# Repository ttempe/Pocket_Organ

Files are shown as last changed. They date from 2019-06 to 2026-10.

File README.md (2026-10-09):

# Pocket Organist

A modern musical instrument instrument that fits in your pocket

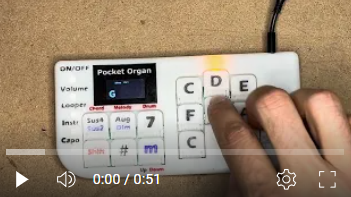
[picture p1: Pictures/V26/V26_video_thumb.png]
Main features (https://youtu.be/aTIo758k2n8)


https://www.facebook.com/Thomass-pocket-organ-109581037453852

https://archive.org/details/hopeconf2020/20200730_0900_The_Pocket_Organ.mp4

https://www.youtube.com/watch?v=AYvCeNSxtIc&list=PLIjRtindY5dAYAr6EwiWz4Ym5uZk0-Hvn

Most instruments we play today are designed around the manufacturing constrains of hundreds of years ago.
Newer instruments are often electronic versions, with the same or similar user interface.

Most really novel instruments are either:
1. excellent, but expensive small-volume brand-name products that only a dedicated musician would buy (eg: the Roli Seaboard, the Dualo Du-Touch, the Hang steel drum, the Sylphyo electronic woodwind, Artiphon Instrument 1, Jamstik ...)
2. cheap, but not good enough for a musician, lacking in depth and/or playability (eg: the roll-up keyboards, stylophone, Otamatone...)

It doesn't have to be that way, though.

The aim of this project is to develop a real musical instrument that:
* is easier to learn and play than most instruments out there
* is so affordable that aspiring musicians would consider it
* is designed to meet the expectations of real musicians (low latency, continuous expression, advanced features...)
* is convenient and versatile, fitting in your pocket and playable over headphones (includes a synthetizer) or a MIDI workstation.
* is widely available, ideally from multiple manufacturers, under the generic term "pocket organist".

See the general presentation: https://github.com/ttempe/Pocket_Organ/blob/master/Doc/2019-06-22%20Pocket%20Organ.pdf

<<<<<<< HEAD
# Hardware design

* The PCB design is published on: https://lceda.cn/ThomasTempe/Pocket_Musical_Instrument
 * The PCB is two-sided, but all the solderable components are on the same side. It is designed to use 0402 and QFN components, and is unfortunately not practical to home-etch or hand-solder ; however, you can order the PCB for a low price directly from https://szlcsc.com. If you have a China address, you can even have them do prototype pick-and-place soldering for most components (still requires SMT hand-soldering skills to finish, though). 
 * It has a LiPo battery that lasts a few hours, and a USB port for charging, and ultimately for MIDI over USB.
* The V26 enclosure is published on: https://a360.co/3xhmZ2Z and https://a360.co/4cuE1t9

# Hall effect keys: prototypes V23+

I've restarted on a different principle again end-2023.
* the keys are now 3D-printed mechanical keys with a magnet inside
* precise, fast key height is read with an SMT Hall effect sensor under each key
* a combination of spring + rubber band allows to have a nice 2-step pressure curve
* I switched to an RP2040 microrontroller, and am now debating whether to switch to CircuitPython

# capacitive touch keys: prototypes V10+

I've restarted from scratch at the beginning of 2020. This branch has:
* capacitive touch keys, which I'm trying to make somehow analog (currently under experimentation)
* a STM32F405 microcontroller
* I've re-written the whole code in Micropython. See the "Py" directory

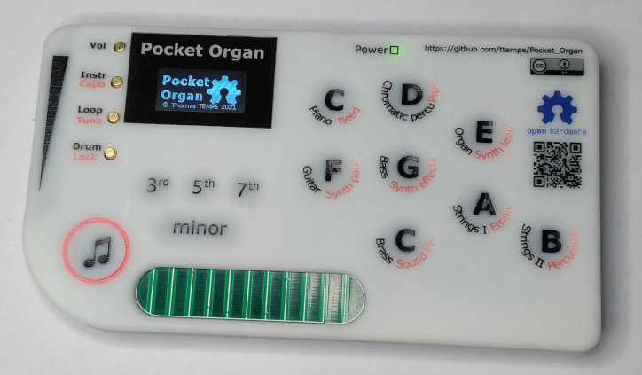
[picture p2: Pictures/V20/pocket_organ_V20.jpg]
Photo of V12 prototype


https://www.youtube.com/watch?v=Pm5AramwmKs&list=PLIjRtindY5dBtU5IU78ZPE2rcO35D6sfV

I've given up this path, as it was difficult to obtain consistent performance on all keys (especially when pressing multiple keys at once), and sourcing sensor ICs was a pain.

# Pressure-sensitive: prototypes V6 to V9

This branch of the project culminated in functional prototypes.
The analog keys use a sheet of Velostat (a pressure-sensitive, conductive plastic) and a silicone keypad.

* The device is built around a micro-controller (currently AtMEGA 32u4) and single-chip MIDI synth (SAM2695).
* code is written in C++, for the Arduino IDE. See the "src" directory.
* It is smaller but thicker than a smartphone (12.5*6*1.5cm)
* The device uses a silicone keypad for all push buttons
 * You can find a 3D model together with the enclosure, and 3D-print it, then use it to cast silicone
 * The process is partly documented here: https://www.instructables.com/id/Analog-Pressure-sensitive-Push-button/
 
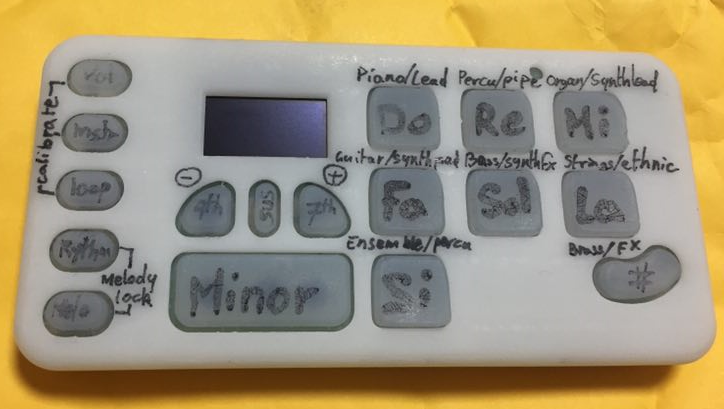
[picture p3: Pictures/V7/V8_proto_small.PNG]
Photo of V8 prototype

 
I've decided to move away from this principle, after:
* realizing that it would be a significant challenge to further lower the key mechanical resistance
* experiencing the Sylphyo's amazingly expressive capacitive touch keys.

=======
>>>>>>> efb6dceb3585c2b404cd15d46e78a298413a9809
# Musical design

This is still work in progress; and probably the most interesting part of the project.

You can play a lot of nice tunes on a piano; but they all require multiple fingers. If you come to a piano with just one finger, the result is likely to sound unpleasant.

In building the user interface, I'm trying to spare some fun for each level of play. This is why it will play chords by default. Chords are undemanding, gratifying, and you can probably find your favourite song on any tablatures repository.

More advanced play (playing one note at a time, adding expression, more exotic chord shapes...) are all there waiting for you to build up your dexterity and coordination; each step takes one more finger to play.

My ultimate goal is that the design of the instrument should progressively nudge the player on the first steps of his musical path. Each successive step should bring additional challenge, and more reward. After a few months, an assiduous player should feel confident to move to his second instrument. But if I've done my job right, the pocket organist will remain an instrument of choice.

# Features

* Under the right hand, there is one analog key for each note of the diatonic scale (Do~Si; plus a second Do). Half-tones are obtained by pressing down two adjacent notes. The keys are laid out such that notes separated by full tones are side-by-side (Do-Re-Mi, Fa-Sol-La-Si, Do).
* Under the left hand are chord shape keys, a "shift" key, and a volume slider.
* Lastly, there is a "strumming comb" slider at the bottom, that allows to easily play multiple notes of the current chord.

Additional features include:
* an 8-track looper (with color backlight codes under the note keys, similar to the Dualo Du-Touch)
* a small OLED display, to serve as a feedback loop. It will ease musical exploration and progressive disclosure by displaying the name of the note/chord being played, and name the features being used.
* function keys allow to select the instrument from the MIDI bank, tune the pitch, transpose, access the looper, and change to melody or drum pad mode.

# The end game

An Open Source Software is easy to publish: you just put it on GitHub, and call it a day. A hardware project means every single unit needs to be manufactured, ideally in a cost-effective way. 

My objective is to put 1 million devices in the hands of prospective players. That will take investment in manufacturing, distribution, and above all marketing, all things that are not in my realm.

I see myself as the person who will develop a product, then set the conditions right so that others may do the manufacturing and distribution. That means building a community, building the word-of-mouth, generating enthusiasthm and possibly looking for partners for distribution and marketing. And then, let them run away with it, and hopefully make money. The product will not reach its users unless someone makes money at every step of the process. I'm the only one who is expected to work for free. And maybe you, the supporter, the enthusiast, the player.

The project's open source nature may be a boon, or a hindrance. I might close back the source, strategically, if I think it can help someone else sell the product. Ultimately, it is better for it to be universally available as black-box commodity than open source on a dusty Github page.

# Hardware design

## Principle

Versions V23 (end-2023) and later rely on Hall effect sensors for the keys
* the key mechanism is 3D-printed.
* Each key has a magnet inside
* A silicone pad under the keys creates a smooth tactile feedback, while allowing for over- or under-pressing.
* precise, fast key height is read with an SMT Hall effect sensor under each key

These versions use an RP2040 microrontroller running CircuitPython

## Resources

* A video walk-through of how to assemble the instrument: https://youtu.be/AYvCeNSxtIc

## Main components

* The PCB design is published on: https://lceda.cn/ThomasTempe/Pocket_Musical_Instrument
 * The PCB is two-sided, but all the solderable components are on the same side. It is designed to use 0402 and QFN components, and is unfortunately not practical to home-etch or hand-solder ; however, you can order the PCB for a low price directly from https://szlcsc.com. If you have a China address, you can even have them do prototype pick-and-place soldering for most components (still requires SMT hand-soldering skills to finish, though).
 * It has a LiPo battery that lasts a few hours, and a USB port for charging, and ultimately for MIDI over USB.
* The enclosure design is published on: https://a360.co/2Yl1HuQ

# Older versions

## capacitive touch keys: prototypes V10+

I've restarted from scratch at the beginning of 2020. This branch has:
* capacitive touch keys, which I'm trying to make somehow analog (currently under experimentation)
* a STM32F405 microcontroller
* I've re-written the whole code in Micropython. See the "Py" directory

Photo of V12 prototype

I've given up this path, as it was difficult to obtain consistent performance on all keys (especially when pressing multiple keys at once), and sourcing sensor ICs was a pain.

## Pressure-sensitive: prototypes V6 to V9

This branch of the project culminated in functional prototypes.
The analog keys use a sheet of Velostat (a pressure-sensitive, conductive plastic) and a silicone keypad.

* The device is built around a micro-controller (currently AtMEGA 32u4) and single-chip MIDI synth (SAM2695).
* code is written in C++, for the Arduino IDE. See the "src" directory.
* It is smaller but thicker than a smartphone (12.5*6*1.5cm)
* The device uses a silicone keypad for all push buttons
 * You can find a 3D model together with the enclosure, and 3D-print it, then use it to cast silicone
 * The process is partly documented here: https://www.instructables.com/id/Analog-Pressure-sensitive-Push-button/
 
Photo of V8 prototype
 
I've decided to move away from this principle, after:
* realizing that it would be a significant challenge to further lower the key mechanical resistance
* experiencing the Sylphyo's amazingly expressive capacitive touch keys.

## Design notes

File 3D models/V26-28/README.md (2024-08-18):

# 3D models

Here are:
* the 3D models for printing (keys have been attached to the shell, for easier printing)
* the Fusion360 archive, for editing.

You will need to use a resin, MJF or similar printer, with a precision ~0.1mm or better.

Additionally, you will need:
* 14 cylindrical magnets, diam. 3mm, 2mm high ; North and South poles normal to the flat sides. Insertion direction is critical (test them with keyboard.monitor_readings() before inserting them, as they're a pain to get out). I get them from [the Zave Taobao shop](https://detail.tmall.com/item.htm?id=619016855032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..) (直径3mm*厚2mm)
* 14 6*7*4mm silicone key pads. I get them from [this Taobao shop](https://item.taobao.com/item.htm?id=19156845663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..)
* A custom printed 40mm*26mm*0.6mm cover plate (screen protector)

Here is an Instructable I wrote on [how to fill the lettering on the top cover](https://www.instructables.com/Writing-High-contrast-Text-on-a-Resin-3D-Print/)

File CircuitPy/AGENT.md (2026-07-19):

# Pocket Organist — Agent Guide

CircuitPython firmware for a portable MIDI chord organ with hall-effect keys, OLED display, and on-board or USB MIDI out. Targets **RP2040** (no FPU); current hardware revision is **V31** (`version.py`).

## Entry point

- `code.py` — bootstraps the app (typically `import pocket_organist`).
- `pocket_organist.py` — main application loop (`PocketOrgan` class).

## Module map

| Module | Role |
|---|---|
| `board_po.py` | **Pin allocation and hardware constants only** — mux GPIO, ADC, buttons, display SPI, MIDI, strum I2C (`strum_i2c`, `STRUM_*`), calibration tables. Import as `import board_po as board`. |
| `mux.py` | MUX shift-register addressing, hall-sensor power (GP4), `vbat_read()` / `vusb_read()`. |
| `keyboard.py` | Hall-key scanning, chord/melody/drum modes, calibration helpers. |
| `display.py` | 128×64 SSD1306 via **displayio** (`auto_refresh=False`; call `disp.refresh()` after updates). |
| `battery.py` | OCV lookup SOC gauge; charging animation via `disp_bat_charging()`. |
| `polyphony.py` | Chord/melody/drum logic and MIDI note output. |
| `looper.py` | Loop recording/playback. |
| `midi.py` | MIDI message helpers (uses `board.midi`). |
| `backlight.py` | NeoPixel key backlight; `backlight_map` in `board_po.py` maps key index to pixel. |
| `bs8112a.py` | Holtek BS8112A-3 I2C driver; `read_keys()` → 12-bit pad mask. |
| `instr_names.py` | GM instrument name tables. |
| `version.py` | Board revision number. |

Legacy / test code lives in `misc/`.

**User-facing documentation:** [`USER.md`](USER.md) — key combinations and feature descriptions for musicians. Keep it in sync when changing UI or controls.

## Application features (agent summary)

| Area | Implementation notes |
|---|---|
| **Modes** | `keyboard.mode`: chord / melody / drum via Shift+3rd/5th/7th. |
| **Volume** | Master vs channel; Shift+Vol at entry or Shift tap while Vol held (`_consume_shift_toggle`). `keyboard.ui_lock` during UI. Startup master = `127 * 75 // 100`. |
| **Capo / tuning** | `loop_capo_or_tune()` — Shift+Capo at entry or Shift tap toggles capo vs tuning. Capo: `polyphony.transpose`. Tuning: GS SysEx, `global_tuning_tenths`, peg*10, Up+Down reset. `ui_lock` throughout. |
| **Instrument** | `loop_instr()` — `high_bank` toggled by Shift tap while Instr held (Shift+Instr at entry = high bank). |
| **Metronome** | `metronome.user_wants` — persists click after looper exit when enabled via Fifth or tap tempo; auto-on from recording arm stops on exit unless `user_wants`. |
| **Looper** | In-memory `TrackStore`; CC7 baked at first note; `leave_looper()` / `apply_ui()` metronome cleanup. |
| **Melody expression** | CC11 on melody channel from key pressure; pitch bend from 7th/m keys. |
| **Display sliders** | `disp_slider()` always updates `text_zones[0].text` (dynamic titles e.g. tuning cents). |
| **Strumming** | 12-pad comb via BS8112A on I2C (GP7 SCL, GP6 SDA, addr 0x50). Hold chord root, touch pads for stacked chord tones; `keyboard.strum_keys` / `polyphony` note on/off. |

## Conventions

- **Always** `import board_po as board` — never bare `import board_po` or `from board_po import …` (except inside `board_po.py` itself).
- **GPIO stays in `board_po.py`**; mux addressing and sensor power live in `mux.py`.
- Hall sensor power: **GP4 high = off**, **GP4 low = on**. Power on before MUX/ADC reads; power off after.
- Display colors for shapes: use `0xFFFFFF` / `0x000000`, not small integers.
- Fonts: PCF in `fonts/`; preload with `font.load_glyphs()` (not dummy `Label`s).
- Battery icon: procedural `Rect` gauge at x=108 in the 8px status bar; persistent (do not clear in `Display.clear()`).
- Keep changes **minimal and focused**; match existing style; avoid drive-by refactors.

## Display layout

- Top **8 px**: status bar (latency ~x=24, battery gauge ~x=108).
- Bottom **56 px**: chord name (large font) or up to 3 lines (medium font) + tips zone.

## Battery

- Single-cell Li-ion (10440), OCV interpolation with **10% reserve** (display 0% at 10% true SOC).
- `battery.py` uses `mux.vbat_read()` / `mux.vusb_read()`; USB ≥ 4.5 V → charging animation.

## Hardware notes

- Analog keys via 3-line MUX + 2 ADCs; calibration in `board.keyb_min` / `board.keyb_range`.
- `keyboard.calibrate()` and `keyboard.test_power_settle()` for bring-up.
- Power: `board.power_off` (GP13), `board.force_on` (GP14).

## What not to do

- Do not commit unless explicitly asked.
- Do not move GPIO out of `board_po.py` or duplicate mux logic outside `mux.py`.
- Do not use `fill=0` on `Rect` borders (renders opaque black on OLED).
- Avoid `pop()`/`append()` on display objects in hot loops without manual refresh batching (causes flicker).

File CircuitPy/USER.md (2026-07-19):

# Pocket Organist — User Guide

Quick reference for controls and features. Hold function buttons while using them; release to exit unless noted.

---

## Power

| Keys | Description |
|---|---|
| **Power** (hold ~0.5 s) | Turn off. Hold again ~0.5 s while off to turn back on (USB power). |

---

## Play modes

Select mode with **Shift** plus one modifier (only one at a time):

| Keys | Mode |
|---|---|
| **Shift + 3rd** | **Chord** — one chord per note key |
| **Shift + 5th** | **Melody** — single-note lines |
| **Shift + 7th** | **Drum** — GM drum hits on note keys |

Press a **note key** (C, D, E, F, G, A, B, …) to play. Release the note key to stop (chord/melody), or use other keys as below.

---

## Chord mode

| Keys | Description |
|---|---|
| **Note key** (hold) | Chord root; name and shape on display |
| **3rd** | Major/minor third (with **m**: sus2 / sus4) |
| **5th** | Perfect / aug / dim fifth (with **m**) |
| **7th** | Add or remove chord 7th |
| **m** | Minor (also affects 3rd/5th modifiers above) |
| **Key pressure** | Expression (CC11) on the held note |
| **Neighbour keys** (expr up/down rows) | Pitch bend while holding the root |
| **Strum comb** (12 pads) | While holding a note key: touch pads to sound stacked chord tones (instead of the auto-arpeggio if any pad is already held). Release the note key to stop |

---

## Melody mode

| Keys | Description |
|---|---|
| **Note keys** | Scale notes (respects capo) |
| **#** | Sharp on the current note |
| **Two adjacent keys** (quick double) | Sharp via slide between neighbours |
| **3rd** | One octave down |
| **5th** | One octave up |
| **Shift** | One octave up |
| **7th / m** (while a note sounds) | Pitch bend up / down |
| **Note key pressure** | Expression (CC11) on the sounding note |

Note names appear on the display while you play.

---

## Drum mode

| Keys | Description |
|---|---|
| **Note keys** | Drum sounds (name on display) |
| **Function keys** | Still work while a drum key is held |

---

## Volume

| Keys | Description |
|---|---|
| **Vol** (hold) | **Master volume** — tap **7th** or **m** (Up/Down) to adjust; harder press = larger step |
| **Shift** (tap while Vol held) | Switch between **master** and **channel** volume (live channels 0 and 1). **Shift + Vol** at entry starts in channel volume |
| | Channel volume blocked while a loop is recording |
| | While Vol is held, note keys and mode changes are ignored |

**Startup default:** master volume 75% (95/127); channel volume 100.

---

## Capo and global tuning

| Keys | Description |
|---|---|
| **Capo** (hold) | **Transpose** by semitones |
| **Note key** | Set capo to that key's pitch class |
| **#** (tap) | Toggle +1 semitone on the chosen step |
| **Shift** (tap while Capo held) | Switch between **capo** and **global tuning**. **Shift + Capo** at entry starts in tuning |
| **7th / m** (Up/Down, in tuning) | Raise or lower tuning (~1-7 cents per firm press) |
| **7th + m together** (in tuning) | Reset to **+0**; frozen until both are released |
| **Release Capo** | Exit; capo changes apply if you adjusted transpose during the session |

Reference pitch is A440 at 0. Tuning affects live play and loop playback. Capo = semitone shift; tuning = fine cent offset.

---

## Instrument

| Keys | Description |
|---|---|
| **Instr** (hold) | Choose MIDI instrument |
| **Note key** | Pick instrument **family** |
| **Shift** (tap while Instr held) | Switch between **low** and **high** instrument banks (eight families each). **Shift + Instr** at entry starts in the high bank |
| **Same or another note key** (second press) | Pick instrument within family; repeat same key to cycle |
| | Not available while recording a loop |

---

## Looper

| Keys | Description |
|---|---|
| **Loop** (hold) | Looper UI; empty slots glow **blue** (hint); recorded slots show red/green/orange status |
| **Note key** (empty slot) | Arm record on that track; metronome starts |
| **Note key** (tap again after release while arming) | Toggle **quick loop** mode (chord taps; metronome paused) |
| **Note key** (recorded track) | Toggle play/stop |
| **Note key** (hold >1.5 s on existing track) | Delete that loop |
| **#** (tap twice) | Tap tempo — two taps set BPM; metronome turns on |
| **7th / m** | BPM +5 / -5 (while in looper) |
| **5th** | Toggle metronome click (can stay on after leaving looper if enabled here or via tap tempo) |
| **Release Loop** | Leave looper |

Up to six loop slots on note keys. Each loop uses its own MIDI channel pair for recording.

---

## Tips

- While **Vol**, **Loop**, **Instr**, or **Capo** is held, actionable keys glow **blue** (left-hand controls and relevant note keys).
- While **Vol**, **Instr**, or **Capo** is held, a quick **Shift** tap switches sub-modes (master/channel, low/high bank, capo/tuning).
- **Shift** at entry still picks the alternate sub-mode; release **Shift** before tapping to switch again.
- **Vol**, **Instr**, and **Capo** UIs block accidental note input and mode changes while active.
- Mode name appears briefly on the display when you change **Shift + 3rd / 5th / 7th**.

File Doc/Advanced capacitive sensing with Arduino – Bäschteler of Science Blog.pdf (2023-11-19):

## Bäschteler of Science Blog (https://bashtelorofscience.wordpress.com/)

bashtelor of science – a blog about my electronics and other creations

# Advanced capacitive sensing with Arduino

…or any other microcontroller.

There are several methods to do capacitive sensing with a microcontroller. The easiest and most common way in the Arduino world is to charge the capacitive probe through a high value reseistor and measuring the time it takes to charge it. While this is indeed a simple method it is highly susceptable to interferance and noise as the wire acts as an antenna due to the high impedance. Also it is not very sensitive compared to other methods but good enough for a simple button.

Here is a video comparing the resistor method to the two methods discussed in this blog post:

The Arduino code I wrote for this demo can be found at the bottom. Here is a close-up shot of the wiring: I soldered the 5MΩ resistor for the ‘resistor method’ directly between pins 8 and 9. The other two sensors are on separate prototyping boards and are connected with wires.

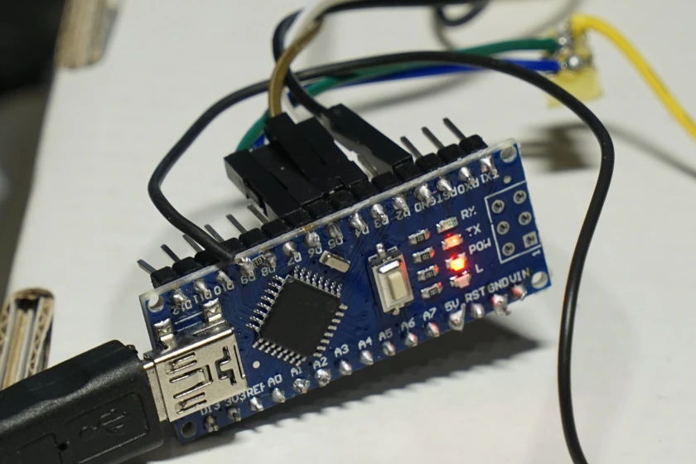
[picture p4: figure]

### Charge transfer method

What is most commonly used in capacitive sensing ICs is the charge transfer method: the capacitor that is to be measured is charged repeatedly through a larger ‘sample’ or ‘reference’ capacitor that accumulates charge. Counting the number of cycles is a measure for the capacitance of the probe. This method can be implemented with two digital pins of a microcontroller and is way more sensitive and very stable. The method is described in detail here. (http://playingwithatmega8.blogspot.com/2014/11/capacitance-measurement.html) Basically this is how it goes:

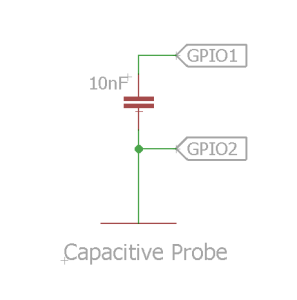
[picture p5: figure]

Both pins are set low to start with, the sample capacitor is discharged.

Step 1: GPIO2 is set as an input, GPIO1 is set to high, charging the the capacitive probe through the 10nF sampling capacitor. Since there is no connection to GND only a tiny amount of electrons flow into the capacitor. How many depends on the capacitance of the probe.
Step 2: GPIO1 is set as an input and GPIO2 is set to GND. This discharges the probe but does not discharging the sampling capacitor as GPIO1 is now floating and no current can flow.

Now repeat the two steps (set GPIO2 floating, set GPIO1 high, etc.) and with each cycle some more charge builds up on the sample capacitor. The voltage on GPIO1 is checked at the end of each cycle until eventually it reaches the ‘high’ trigger level. Counting the number of cycles gives an idea of the capacitance of the probe, it is by no means a good method to measure the exact capacitance as there are ‘stray’ capacitances all over the place influencing an exact measurement but for relative capacitance changes like in a proximity sensor or a capacitive slider switch this works very well.

The sample capacitor should be chosen somewhere between 1nF and 100nF depending on the size of the probe. Choosing a too large capacitor makes the measurement very slow and a too small capacitor will not give a good enough resolution.

### The filter overflow method

I invented this method a few years ago when looking at a design for a capacitive probe. When researching and looking at the schematics of some other methods I had the idea for this circuit:

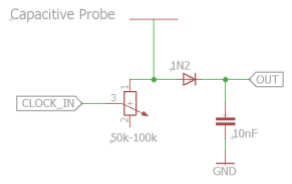
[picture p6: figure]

In addition to the sample capacitor it requires a resistor/potentiometer and a diode with a low capacitance like the very common 1N4148. The input and the output are connected to digital GPIOs of the Arduino, I used D3 as the clock and D4 as the sensing input in the code below. The way it works is quite the opposite way of the charge transfer method. That is also why in the video the two signals go the opposite way. Here is how it works:

Step 1: apply a positive voltage to ‘CLOCK_IN’. The probe is charged quickly through the resistor (the initial sensitivity is adjustable if potentiometer is used) and as soon as it is charged enough the diode will switch on and the current will ‘overflow’ to the bigger capacitor.
Step 2: set the input low and check the output voltage. If the foltage at the output is not yet ‘high’ then repeat.

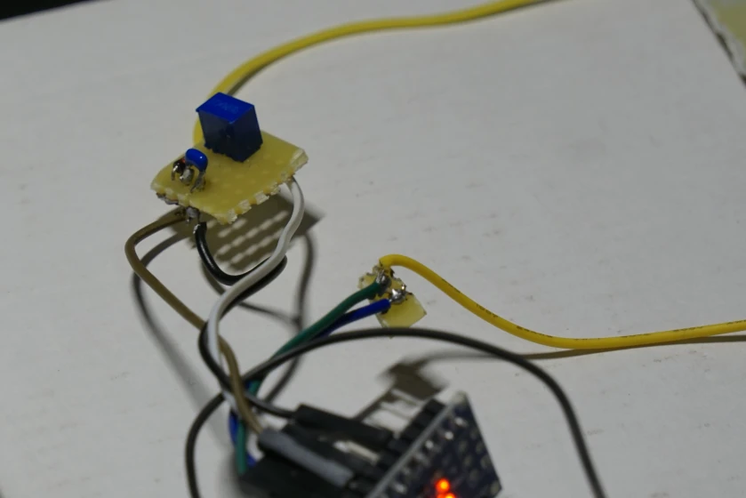
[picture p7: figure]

Filter overflow circuit (back) and charge transfer method using a barely visible SMD cap (front)

For a large capacitance on the probe it takes more cycles than for a small one: the probe acts like a low-pass filter on the signal. The trick is to make the clock fast: the faster it is the more sensitive the probe can be made. If the clock is chosen too fast for a large probe then the diode will stop switching on after a few cycles and the output may never reach ‘high’. At that point the on-time should be increased. This is done in the code by switching to a longer on-time after counting a few hundred (or thousand) clock cycles so there is no infinite loop. In the code below I use the assembler command ‘nop’ which waits exactly one clock cycle or 62.5ns at 16MHz. More ‘nop’ operations can be added to decrease the clock speed.

The ability to choose the sensitivity of the circuit just by changing the on-time is another advantage over the charge transfer method which is fixed in sensitivity without changing the sample capacitor.

If the resistor/capacitor/clock combination is tuned just right the probe can be made very sensitive: I was able to sense my hand as far as 30cm away from the elctrode by using a 51k resistor, a 1nF sampling capacitor and five ‘nop’ in the code with a 30cm long cable as the probe. The noise picked up at this sensitivity is horrible though.

If you want to use multiple probes on a single clock here is how you would wire this up:

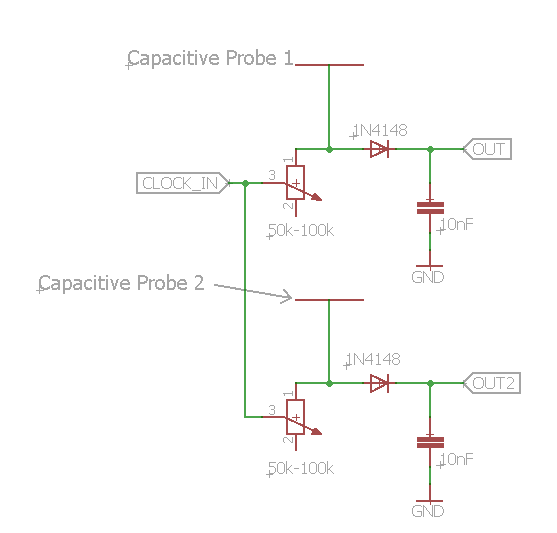
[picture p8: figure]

In the code both outputs have to be checked after the clock line is set low of course. This cascading can be continued with more probes. If the circuit is done with SMD components it can still be made very small on a prototyping board.

### Comparing the waveforms

The stuff above explains how these methods work in theory but let’s look at what the voltages actually look like. It may help to understand what is going on in the world of electrons. The photo shows a ‘behind the scenes’ shot of the setup used in the demo video: the copper clads used to be taped to a wooden surface, hence the dirty look on the bottom side. This setup was also used to take the shots below.

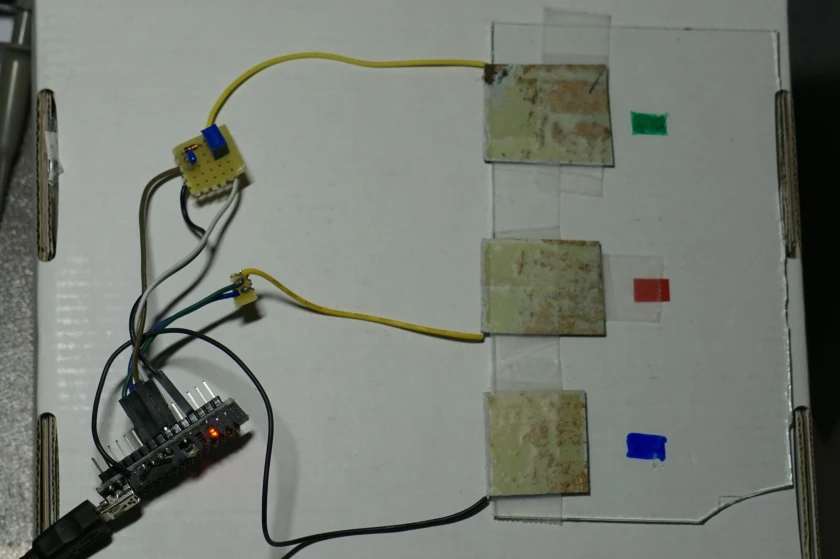
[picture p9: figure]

First off the resistor method. The blue signal shows the voltage being set to high, then the capacitive probe starts charging through the resistor. Once the pin is charged up, the software takes the time and sets both pins low. The video shows this in action: when I touch the glass plate with my finger the charging time increases as the capacitance of the probe gets bigger but also there is a lot of jitter picked up as my body acts as an antenna bringing the noise close to the circuit. So why is only this circuit so susceptible to this noise? Because of the high resistor value it takes very little AC-currents to cause large voltages on the circuit. The other circuits do not use such large resistors so they can just ‘eat up’ that current without causing much noise.

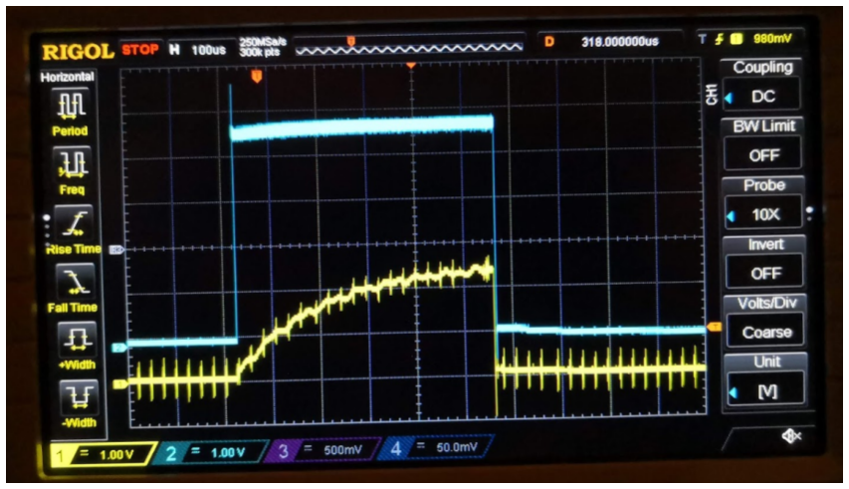
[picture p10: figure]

The charge transfer method has a completely different approach: it uses a clocked circuit and is more ‘digital’ and hence also very stable. The screenshot shows the charging up of the capacitor. Channel1 (yellow) shows the voltage pattern on the GPIO1 pin: the lower end increases with every cycle until the Arduino pin triggers as ‘high’. Channel2 (blue) on the other hand shows the voltage at the probe which is zero when set to low and shows the difference between 5V and the sample capacitor voltage when left floating, so it looks like a mirror image of channel1. Each time channel 1 is set to high the current flows through the sample capacitor into the probe, charging the sample capacitor up by a little bit.

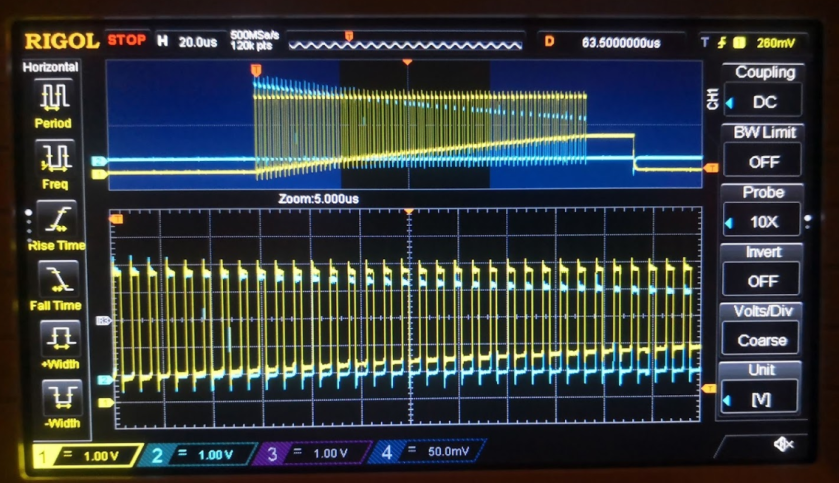
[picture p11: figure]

Again, the video shows how it behaves when I touch the glass plate: as the capacitance of the copper plate increases the number of cycles it takes to charge up the sample capacitor decreases.

The third method is probably a bit more complicated to understand. The yellow line shows the clock input. The current through the resistor (or potentiometer) charges up the capacitive probe very quickly: you can barely see the blue curve rising more slowly than the yellow line. Once it reaches a voltage higher than the sampling capacitors voltage (channel 3 in purple) the diode starts conducting and charging the sampling capacitor up some more. See how the blue and purple lines start rising in parallel. When the clock is set low the probe is discharged. Also note how the sampling capacitor loses just a tiny bit of charge as well. This is due to leakage currents. If the clock is too fast for the size of the capacitive probe you can imagine that this game can reach an equilibrium state before the sampling capacitor is charged enough to trigger the ‘high’ level at about 2.5V.

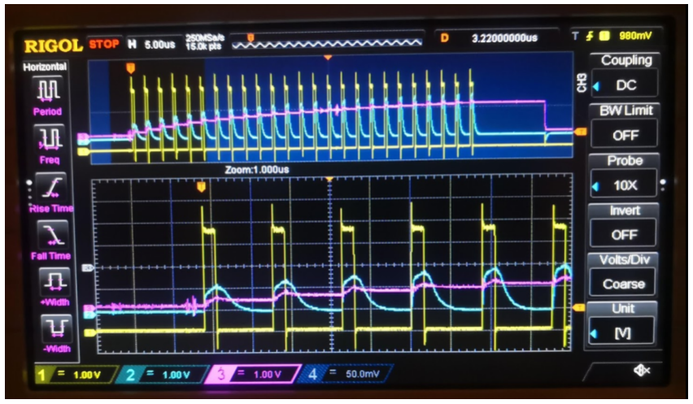
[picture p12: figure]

In contrast to the ‘charge transfer method’ you can see that the number of clocks it takes when coming close to the glass plate increases. So this method could be viewed as a combination of the resistor method and the

## One thought on “Advanced capacitive sensing with Arduino”

Thomas (https://github.com/ttempe/Pocket_Organ)

March 10, 2020 at 1:40 am

Wow, very nice!
Thanks a lot. I’m going to try that next on my musical instrument project https://github.com/ttempe/Pocket_Organ

charge transfer method as it takes the best from both circuits: it uses only one pin per additional channel (like the resistor method) but has the stability and sensitivity of the charge transfer method.

### Arduino Code

I put the example I used to create the video at the top up on git: Arduino Code (https://gist.github.com/DedeHai/3d3d9854d9c6a329496ff6d7e4b23e0c)

I hope you enjoyed this little (or rather lengthy?) lesson about capacitive sensing. If you have any suggestions or questions please leave a comment.

bashtelorofscience (https://bashtelorofscience.wordpress.com/author/bashtelorofscience/) / February 8, 2019 (https://bashtelorofscience.wordpress.com/2019/02/08/advanced-capacitive-sensing-with-arduino/)

Like (https://bashtelorofscience.wordpress.com/2019/02/08/advanced-capacitive-sensing-with-arduino/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)

Bäschteler of Science Blog (https://bashtelorofscience.wordpress.com/) / A WordPress.com Website. (https://wordpress.com/?ref=footer_custom_acom)

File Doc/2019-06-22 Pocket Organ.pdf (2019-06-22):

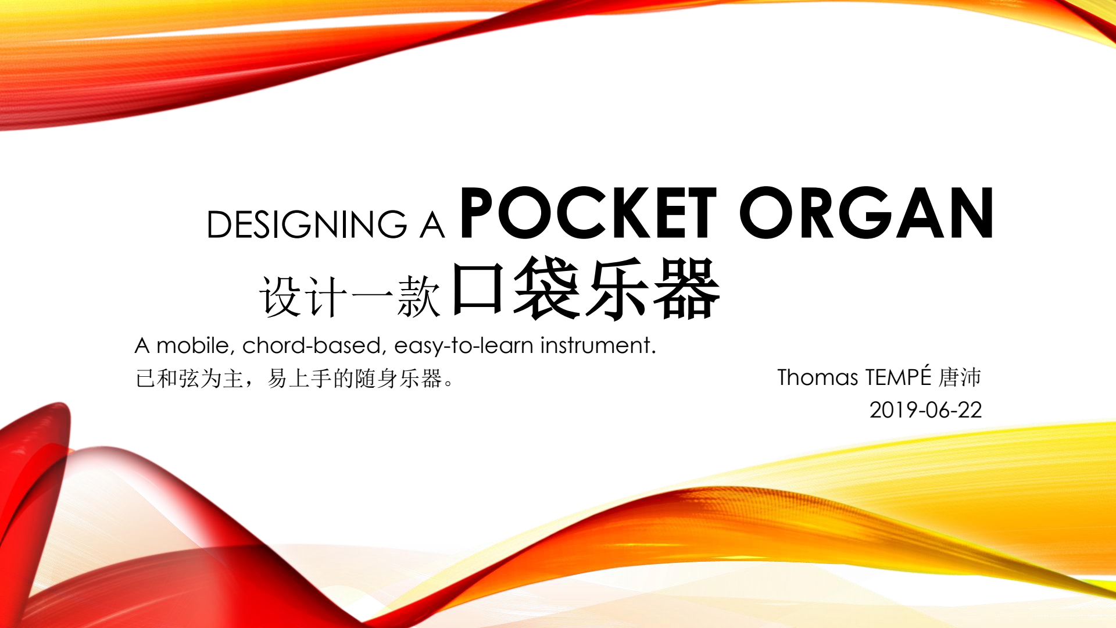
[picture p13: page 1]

# DESIGNING A POCKET ORGAN

# 设计一款口袋乐器

A mobile, chord-based, easy-to-learn instrument.
已和弦为主，易上手的随身乐器。 | Thomas TEMPÉ 唐沛
| 2019-06-22

# DESIRABLE ATTRIBUTES

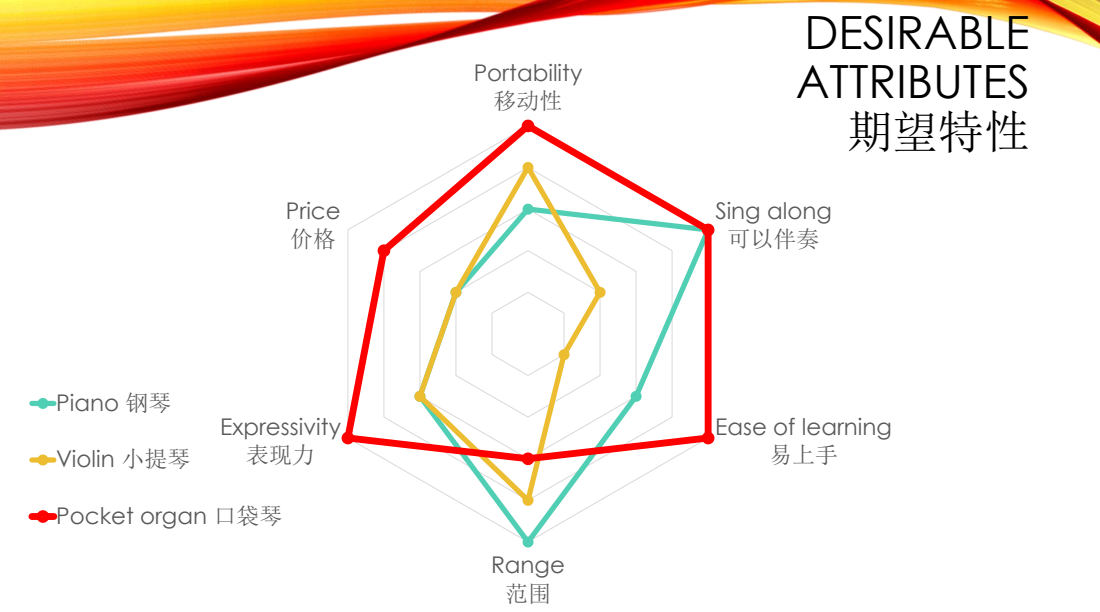
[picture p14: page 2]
Portability 移动性; Sing along 可以伴奏; Range 范围; Expressivity 表现力; Price 价格; Piano 钢琴; Violin 小提琴; 期望特性

Ease of learning
易上手

Pocket organ 口袋琴

# DESIRABLE ATTRIBUTES

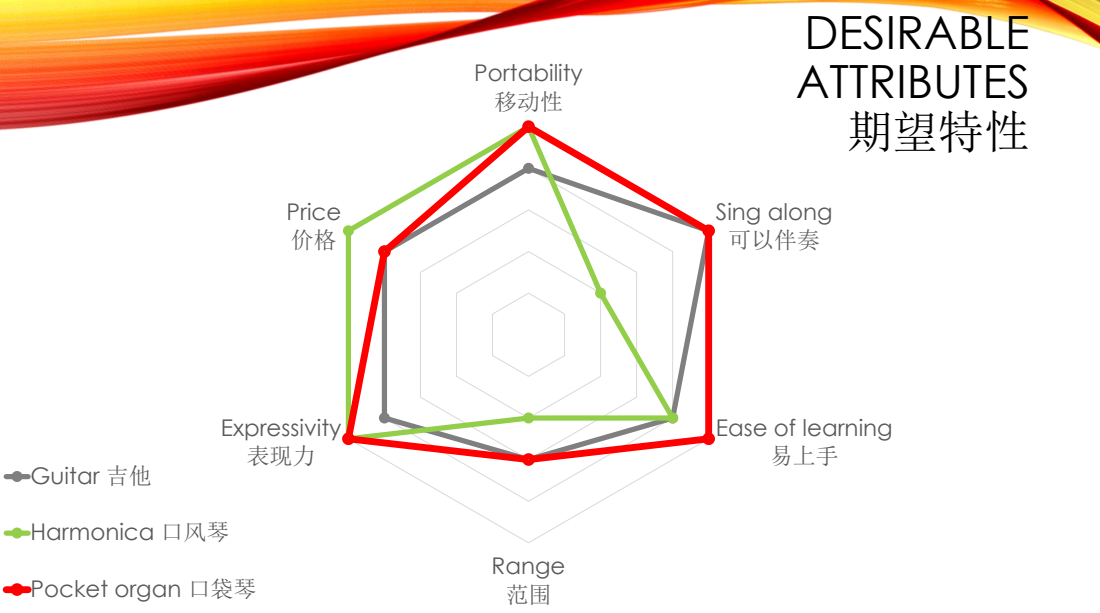
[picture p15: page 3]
Portability 移动性; Sing along 可以伴奏; Range 范围; Expressivity 表现力; Price 价格; Guitar 吉他; Harmonica 口风琴; 期望特性

Ease of learning
易上手

Pocket organ 口袋琴

# USE CASES

用例

Target audience:
目标者：
- Beginner musicians

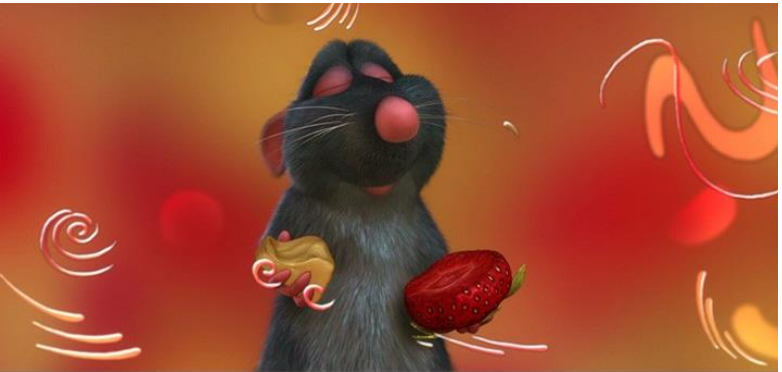
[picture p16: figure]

Use cases:
用例：
- Practice on the go
随时随地锻炼
- Play as you sing
边唱边弹
- Accompany friends singing 小卷伴奏

# INSTRUMENT LAYOUT

# 乐器的样子

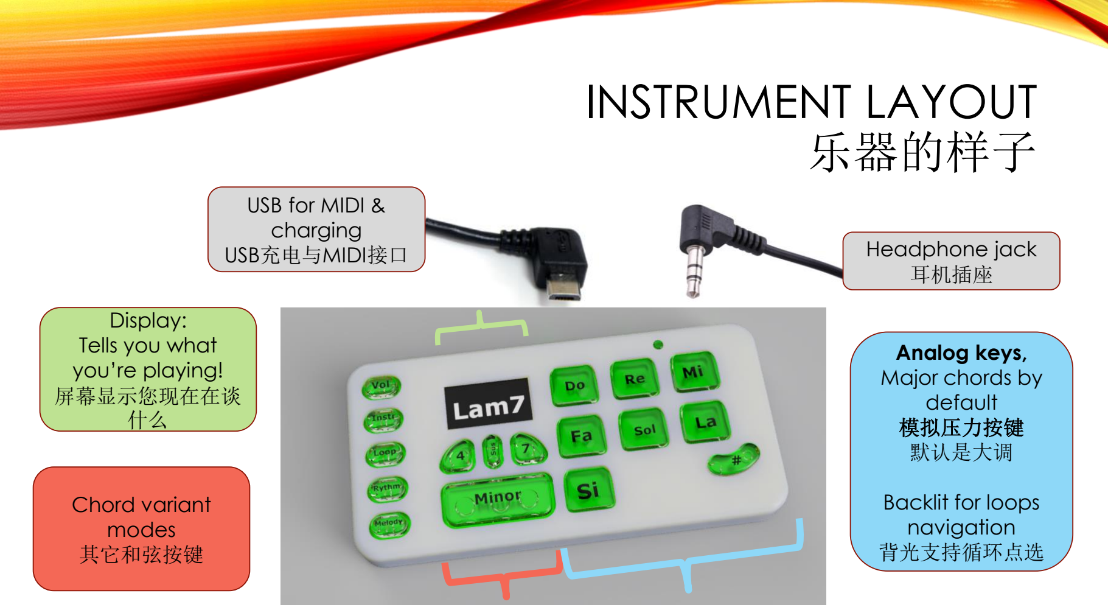
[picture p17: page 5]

Analog keys,
Major chords by
default
模拟压力按键
默认是大调

Backlit for loops
navigation
背光支持循环点选

Chord variant
modes
其它和弦按键

USB for MIDI &
charging
USB充电与MIDI接口 | Headphone jack
| 耳机插座

Display:
Tells you what
you’re playing!
屏幕显示您现在在谈
什么

## PLAYS LIKE A GUITAR (ONLY, EASIER)

# 比吉他还容易

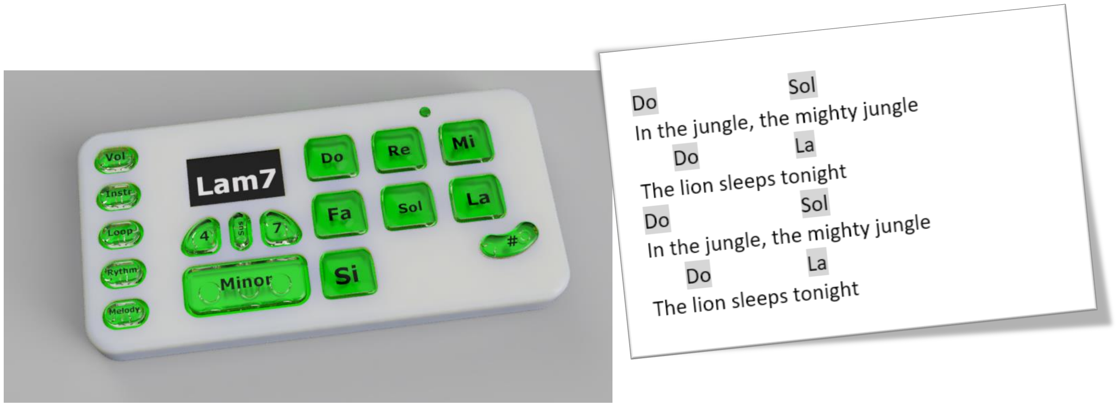
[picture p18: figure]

# CURRENT PROTOTYPE

# 先有的样件

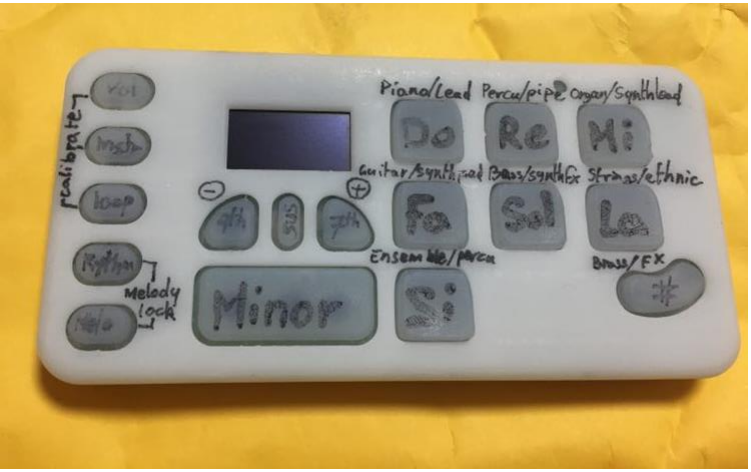
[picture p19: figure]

What’s working
已实现
- Analog buttons expression 模拟按键与表现力
- Chords & melody
和弦与单音模式
- Midi synth & battery
合成器与电池
- Midi USB
- 3D-printed enclosure,
home-cast silicone
keyboard
外壳是3D打印，硅胶键盘用
3D打印的模具

# ANALOG VELOSTAT KEYS

# 模拟按键

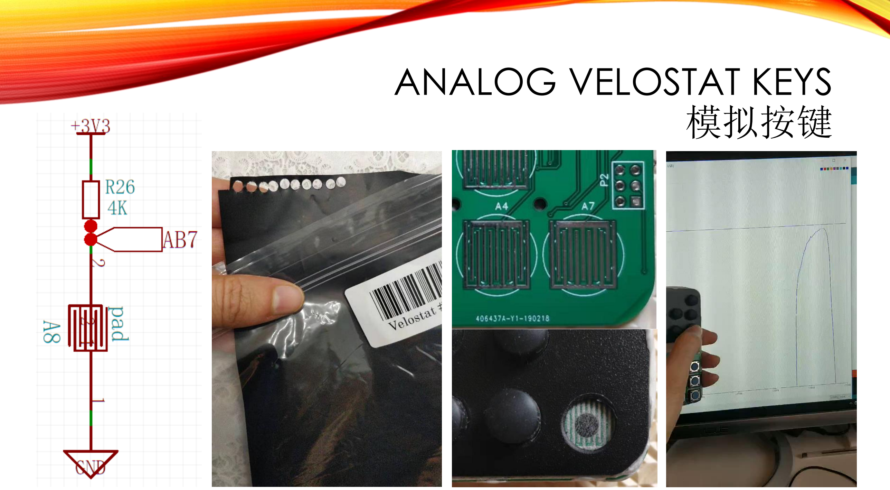
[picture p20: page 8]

# THANK YOU

谢谢

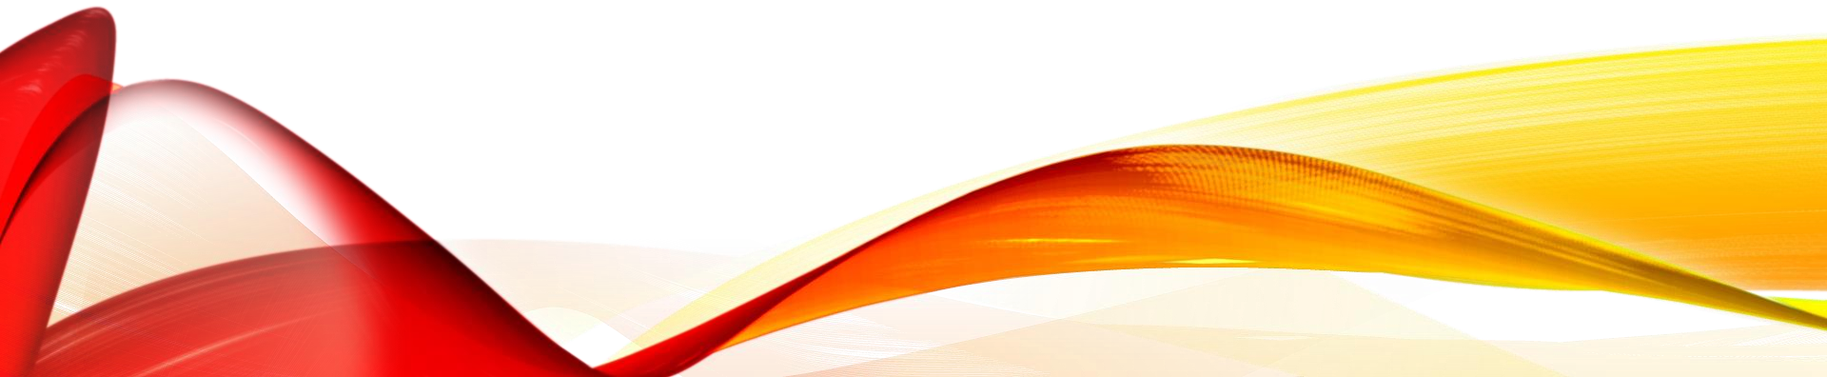
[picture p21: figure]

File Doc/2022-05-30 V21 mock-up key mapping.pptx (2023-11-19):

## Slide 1

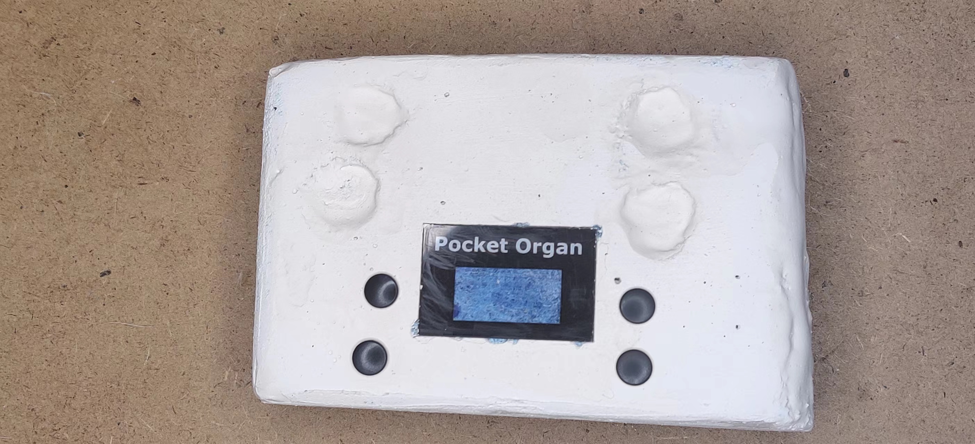
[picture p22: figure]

Melody
Up

Drum
Down

Octave+
Up

Octave-
Down

Volume

Instr.

Loop

Capo

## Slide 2

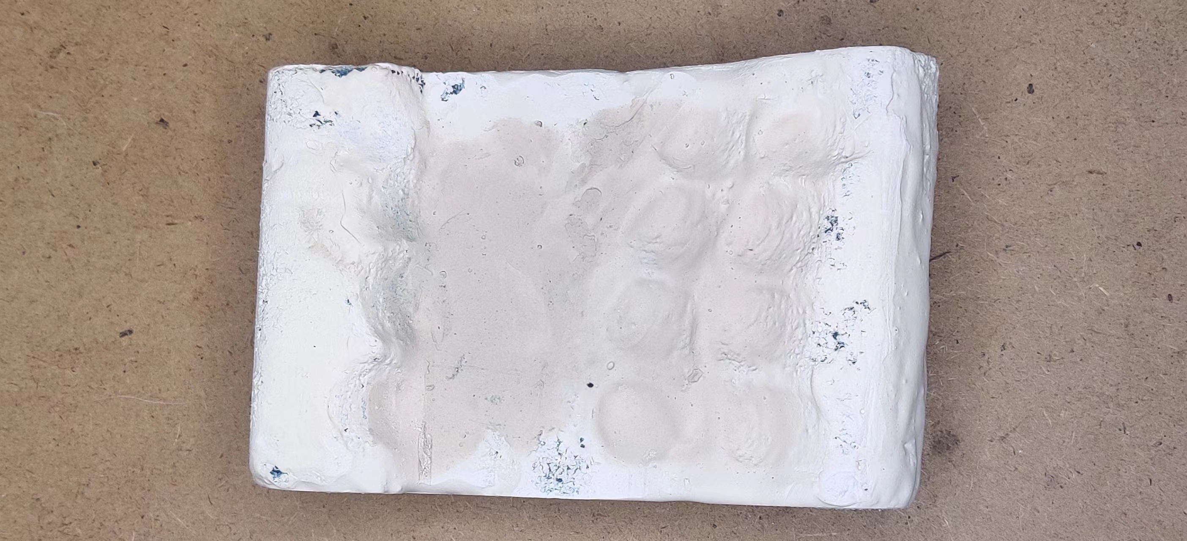
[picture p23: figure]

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
Minor

C

F

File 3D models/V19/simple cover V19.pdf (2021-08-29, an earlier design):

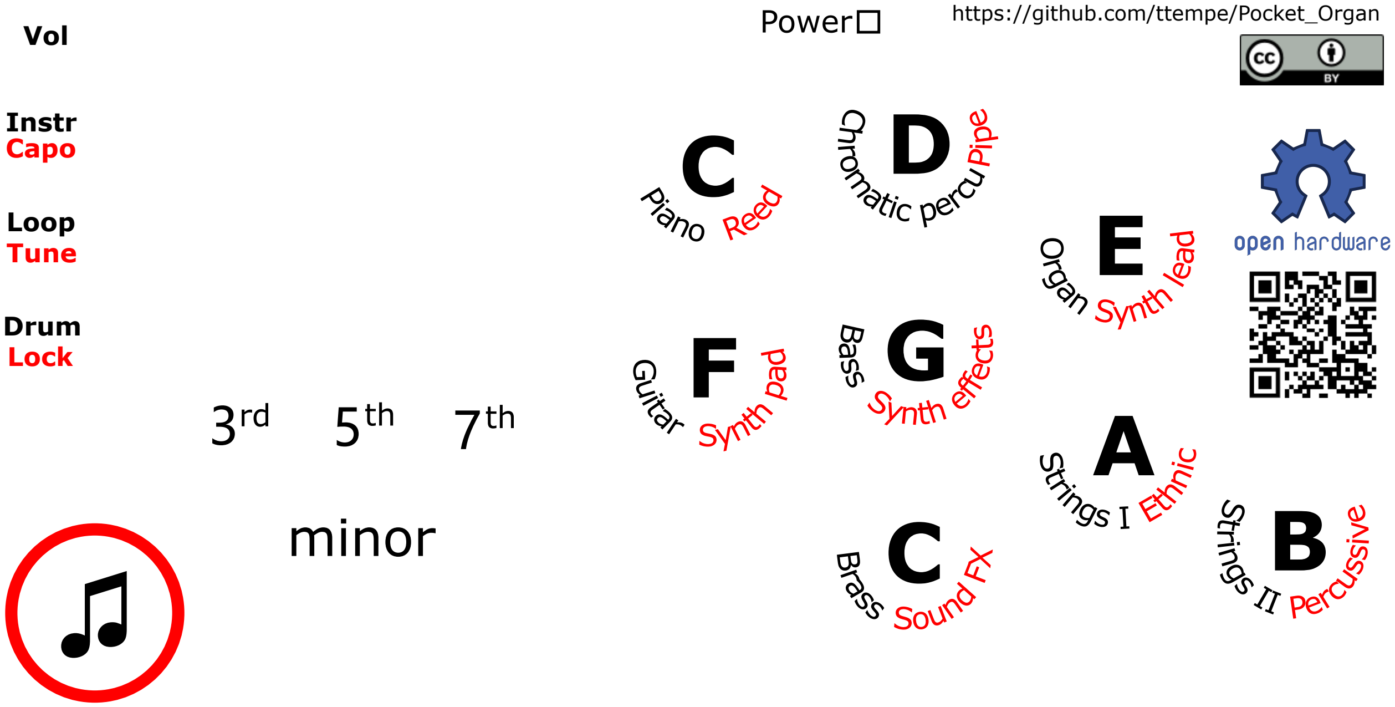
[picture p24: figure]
minor; Power; Vol; Instr Capo; Loop Tune; Drum Lock; Piano; Chromatic percu; Organ; Guitar; Bass; Strings I Strings II; Brass; Reed; Pipe; Synth lead; Synth pad; Synth effects; Ethnic; Percussive; Sound FX; https://github.com/ttempe/Pocket_Organ

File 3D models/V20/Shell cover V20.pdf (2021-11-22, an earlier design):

### Instr

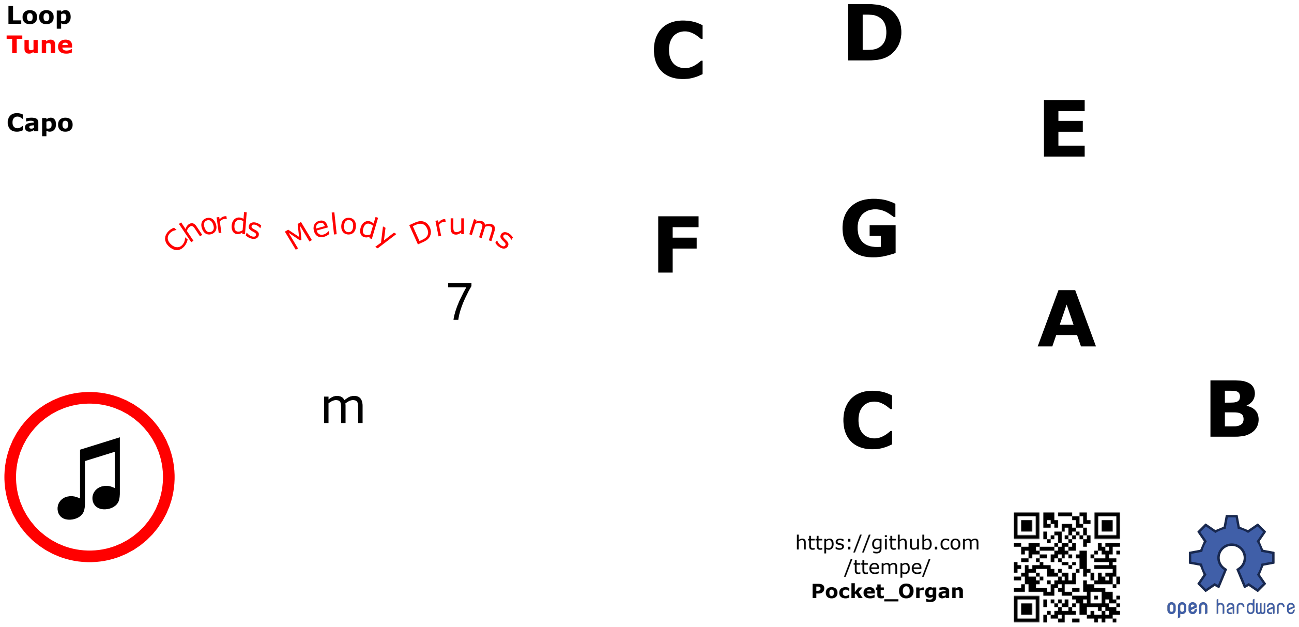
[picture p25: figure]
Capo; Loop Tune; Chor ds; https://github.com /ttempe/ Pocket_Organ

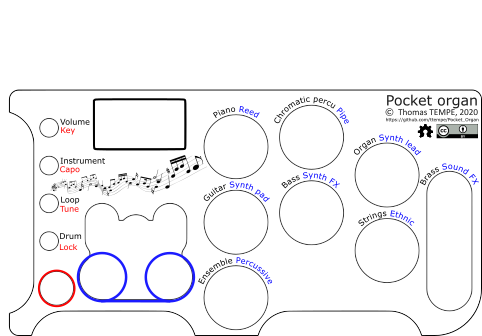
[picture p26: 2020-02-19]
3D models/V11 mock-up/cover plate design.png

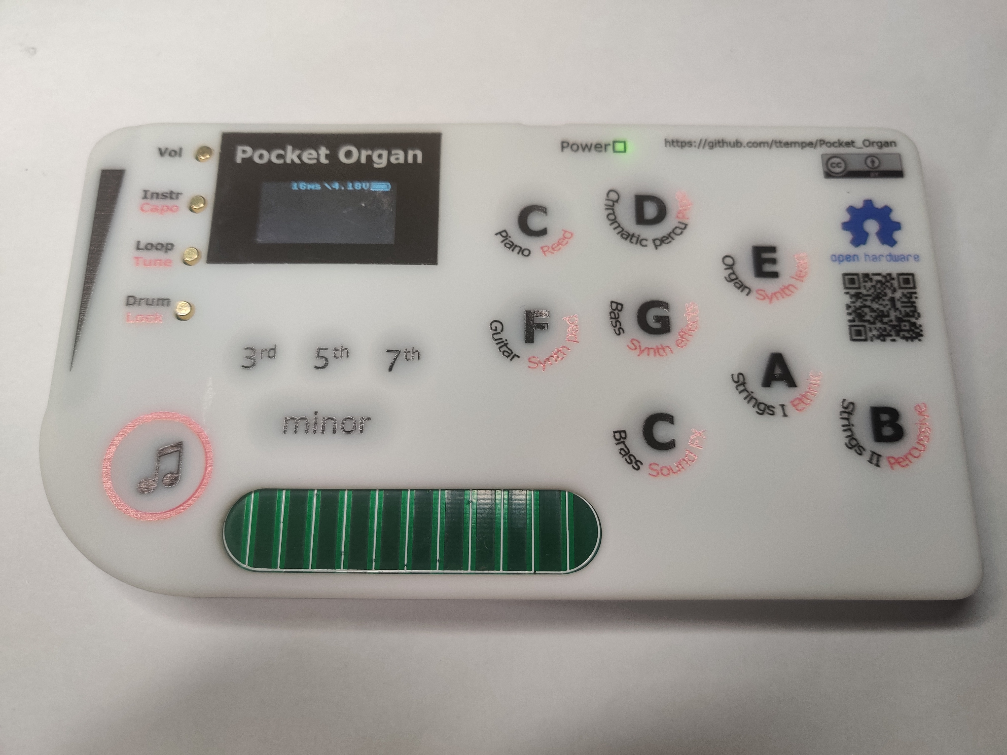
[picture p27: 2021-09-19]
Doc/2021-08-28 V19B/微信图片_20210825201348.jpg

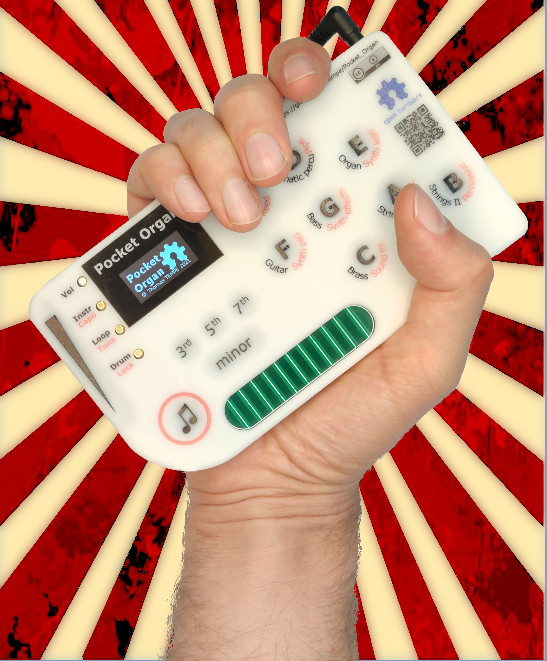
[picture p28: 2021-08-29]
Doc/2021-08-28 raised fist.jpg

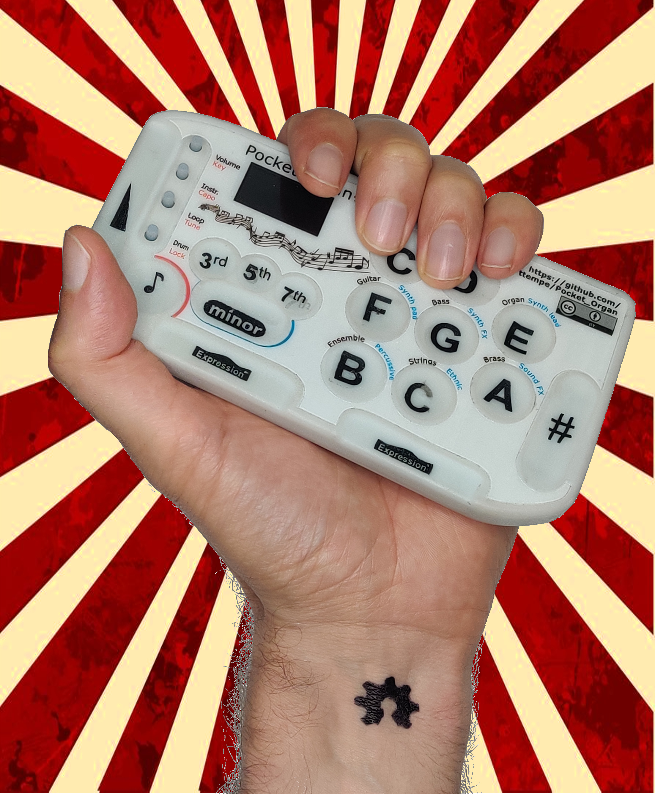
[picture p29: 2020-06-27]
Doc/2020-06-26 raised fist.jpg

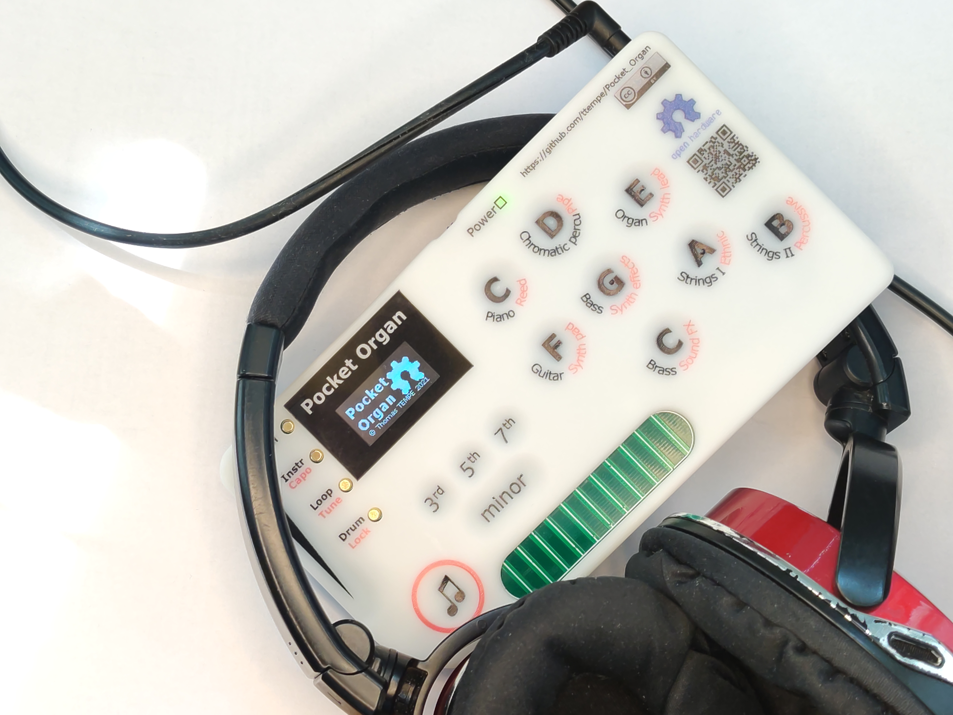
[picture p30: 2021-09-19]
Doc/2021-08-28 V19B/微信图片_20210828122737.jpg

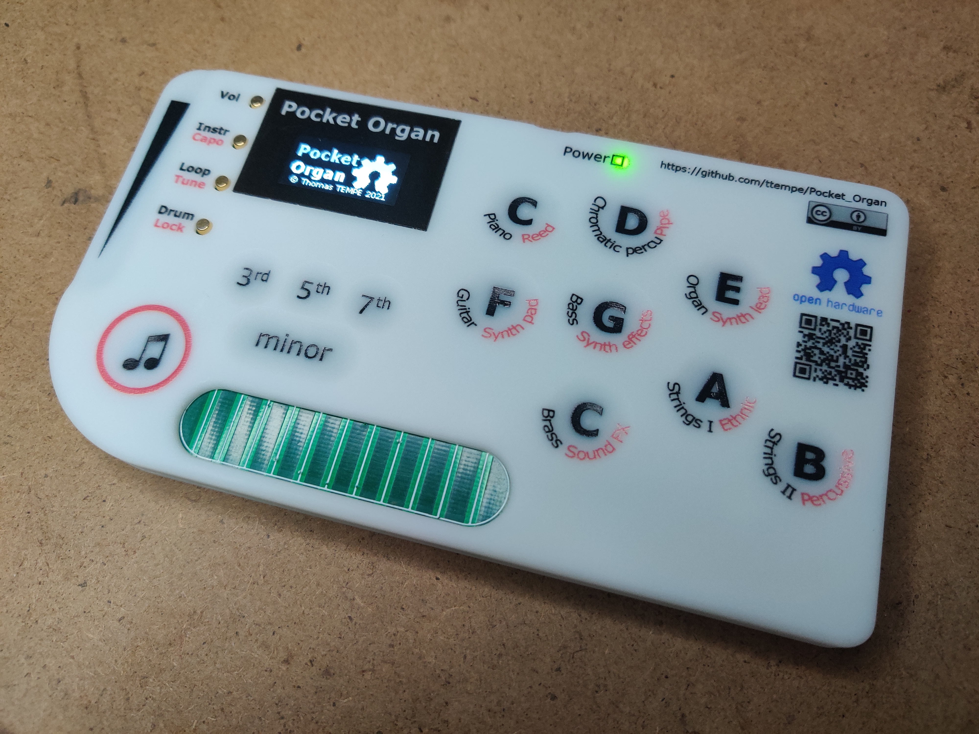
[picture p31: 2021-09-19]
Doc/2021-08-28 V19B/微信图片_20210828121010.jpg

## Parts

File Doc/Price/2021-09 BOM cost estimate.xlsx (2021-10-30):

 |  | Update date | 2021-09-25
 |  | Latest HW version | V19
Item | Qty | Unit Cost (10 pcs) | Unit cost (1000 pcs)
Microcontroller | 1 | ¥125 | ¥80
Capacitive sensor | 3 | ¥12 | ¥8
Display | 1 | ¥18 | ¥14
MIDI synth | 1 | ¥15 | ¥14
PCB | 1 | ¥8 | ¥4
Misc. components | 1 | ¥24 | ¥16
Battery | 1 | ¥16 | ¥12
Window | 1 | ¥2.8 | ¥0.5
Shell (3D printed) | 1 | ¥25 | ¥25
Shell marking | 1 | ¥25 | ¥2
Total (RMB) |  | ¥294.8 | ¥191.5 | ¥228.00 | ¥112.00
Total (USD) |  | $49.13333333 | $31.91666667
Estimated market price |  | ¥1474 | ¥957.5
 |  | $245.6666667 | $159.5833333
 |  |  |  |  | ¥32700.00
 |  |  |  |  | ¥7000.00
 |  |  |  |  | ¥5.00
 |  |  |  |  | ¥9.67

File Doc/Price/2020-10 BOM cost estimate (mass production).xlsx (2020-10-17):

 |  | Update date | 2020-10-17
 |  | Latest HW version | V16
Item | Qty | Unit Cost (10 pcs) | Unit cost (1000 pcs)
Microcontroller | 1 | ¥32 | ¥23
Capacitive sensor | 3 | ¥15 | ¥8
Display | 1 | ¥18 | ¥14
MIDI synth | 1 | ¥15 | ¥14
PCB | 1 | ¥8 | ¥4
Misc. components | 1 | ¥24 | ¥16
Battery | 1 | ¥16 | ¥12
Shell | 1 | ¥50 | ¥3
Printed cover | 1 | ¥20 | ¥2
Total (RMB) |  | ¥228 | ¥112
Total (USD) |  | $38 | $18.66666667
Estimated market price |  | ¥560
 |  | $93.33333333

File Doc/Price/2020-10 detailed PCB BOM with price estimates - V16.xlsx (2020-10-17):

ID | Name | Designator | Footprint | Quantity | Manufacturer Part | Manufacturer | Supplier | Supplier Part | LCSC Assembly | Price (10) | Price (1000)
1 | USB_OTG | P2 | MICRO_USB_C10418 | 1 |  |  | LCSC | C10418 |  | ¥0.30 | ¥0.22
2 | TP4057 | IC2 | SOT-23-6 | 1 | TP4057 | TOPPOWER | LCSC | C12044 |  | ¥0.70 | ¥0.47
3 | 10k | R52 | 402 | 1 | 0402WGF1002TCE | UniOhm | LCSC | C25744 |  | ¥0.01 | ¥0.01
4 | 10u | C32,C45,C59,C56 | 402 | 4 | CL05A106MQ5NUNC | SAMSUNG | LCSC | C15525 |  | ¥0.05 | ¥0.04
5 | 100n | C33,C44,C58,C49,C57,C55,C54,C53,C52,C60,C62,C61,C64,C46,C43,C40,C35,C67,C68,C69,C7,C31,C10 | 402 | 23 | CL05B104KO5NNNC | SAMSUNG | LCSC | C1525 |  | ¥0.01 | ¥0.01
6 | SAM2695
7 | 4.7u | C48 | 402 | 1 | CL05A475MP5NRNC | SAMSUNG | LCSC | C23733 |  | ¥0.05 | ¥0.04
8 | 47k | R54,R53,R2,R12,R13,R51,R55,R58,R63,R68,R70 | 402 | 11 | 0402WGF4702TCE | UniOhm | LCSC | C25792 |  | ¥0.01 | ¥0.01
10 | 220 | R64,R66,R72,R76,R79,R81,R83,R56,R78,R80,R82,R84,R65,R69,R73,R85,R86 | 402 | 17 | 0402WGF2200TCE | UniOhm | LCSC | C25091 |  | ¥0.01 | ¥0.01
11 | 1k | R57,R1 | 402 | 2 | 0402WGF1001TCE | UniOhm | LCSC | C11702 |  | ¥0.01 | ¥0.01
12 | 1 | R47,R48 | 402 | 2 | 0402WGF100KTCE | UniOhm | LCSC | C25086 |  | ¥0.01 | ¥0.01
13 | 2.2u | C51,C47 | 603 | 2 | CL05A225MQ5NSNC | SAMSUNG | LCSC | C23630 |  | ¥0.05 | ¥0.01
14 | 1u | C36,C37,C38,C39,C3,C1 | 402 | 6 | CL05A105KA5NQNC | SAMSUNG | LCSC | C52923 |  | ¥0.05 | ¥0.01
15 | 22 | R5,R7 | R0402 | 2 | 0402WGF220JTCE | UniOhm | LCSC | C25092 | Yes | ¥0.01 | ¥0.01
16 | 19-213/Y2C-CQ2R2L/3T(CY) | LED2-Y | LED0603-R-RD | 1 | 19-213/Y2C-CQ2R2L/3T(CY) | EVERLIGHT | LCSC | C72038 | Yes | ¥0.11 | ¥0.08
17 | SRV05-4-P-T7 | TV1 | SOT-23-6_L2.9-W1.6-P0.95-LS2.8-BR | 1 | SRV05-4-P-T7 | PROTEK | LCSC | C85364 | Yes | ¥1.10 | ¥0.65
18 | 12MHz | X1,X3 | OSC-SMD_4P-L3.2-W2.5-BL | 2 | X322512MSB4SI | YXC | LCSC | C9002 | Yes | ¥0.40 | ¥0.40
19 | Reverse bicolor LED | LED12,LED15,LED16,LED17,LED18,LED19,LED20,LED21,LED22,LED3 | LED-SMD_4PIN-L3.2-W1.25-H1.1-TR-TEMPE | 10 | 23-22B/R7G6C-A30/2A | Everlight | LCSC | C131287 |  | ¥0.40 | ¥0.35
21 | 100K | R35,R8,R37,R18,R60,R61,R62 | R0402 | 7 | 0402WGF1003TCE | UniOhm | LCSC | C25741 | Yes | ¥0.01 | ¥0.01
22 | 4.7uF | C4,C5,C6,C8,C9,C13,C14,C15,C18,C19,C20,C21,C23,C24,C25,C26,C27,C28,C66,C70,C71,C72,C73,C74,C75,C76,C78,C22 | C0603 | 28 | CL10A475KO8NNNC | SAMSUNG | LCSC | C19666 | Yes | ¥0.05 | ¥0.04
23 | 20pF | C11,C12 | C0402 | 2 | 0402CG200J500NT | FH | LCSC | C1554 | Yes | ¥0.05 | ¥0.00
24 | SS14 | D4 | SMA_L4.3-W2.6-LS5.2-FD | 1 | SS14 | MDD | LCSC | C2480 | Yes | ¥0.05 | ¥0.05
25 | 10K | R31 | R0402 | 1 | 0402WGF1002TCE | UniOhm | LCSC | C25744 | Yes | ¥0.01 | ¥0.01
26 | XC6206P332MR | U3,U4,U28,U30 | SOT-23-3_L2.9-W1.6-P1.90-LS2.8-BR | 4 | XC6206P332MR | TOREX | LCSC | C5446 | Yes | ¥0.60 | ¥0.37
27 | A2001WR-S-2P | BAT2 | A2001WR-S-2P | 1 | A2001WR-S-2P | Changjiang Connectors | LCSC | C225233 |  | ¥0.60 | ¥0.37
28 | 2.2uF | C2,C79 | C0603 | 2 | CL10A225KO8NNNC | SAMSUNG | LCSC | C23630 | Yes | ¥0.05 | ¥0.01
29 | 200K | R3,R4 | R0603 | 2 | 0603WAF2003T5E | UniOhm | LCSC | C25811 | Yes | ¥0.01 | ¥0.01
30 | 74HC595A | SR3,SR4 | SOIC-16_150MIL | 2 | 74HC595D,118 | Nexperia | LCSC | C5947 |  | ¥0.47 | ¥0.35
31 | AT42QT1110-AUR | U1,U29,U11 | TQFP-32_L7.0-W7.0-P0.80-LS9.0-BL | 3 | AT42QT1110-AUR | Microchip Tech | LCSC | C219838 | Yes
32 | SK-12D02-VG3 | SW2 | DIP-8.6X4.4 | 1 | SK-12D02-VG3 | Rectangular Connectors - Contacts | LCSC | C136723 |  | ¥0.50 | ¥0.32
33 | 4.7uF | C50 | C0402 | 1 | CL05A475MP5NRNC | SAMSUNG | LCSC | C23733 | Yes | ¥0.05 | ¥0.01
35 | 18.2K | R40,R41,R42,R43,R44,R45,R46,R49,R50 | R0402 | 9 | 0402WGF1802TCE | UniOhm | LCSC | C25762 | Yes | ¥0.01 | ¥0.01
36 | 1K | RN11 | RES-ARRAY-SMD_0402-8P-L2.0-W1.0-BL | 1 | 4D02WGJ0102TCE | UniOhm | LCSC | C25726 | Yes | ¥0.01 | ¥0.01
37 | 19-217/GHC-YR1S2/3T | LED4-G | LED0603-R-RD | 1 | 19-217/GHC-YR1S2/3T | EVERLIGHT | LCSC | C72043 | Yes | ¥0.11 | ¥0.08
38 | KXTJ3-1057 | U15 | LGA-12_L2.0-W2.0-P0.50-BL | 1 | KXTJ3-1057 | ROHM Semicon | LCSC | C442603 | Yes | ¥2.80 | ¥1.66
39 | 10pF | C80,C81,C77 | C0402 | 3 | CL05C100JB5NNNC | SAMSUNG | LCSC | C32949 | Yes | ¥0.01 | ¥0.01
40 | KT-0603R | LED1 | LED0603-FD | 1 | KT-0603R | KENTO | LCSC | C2286 | Yes | ¥0.11 | ¥0.08
41 | 100uF | C41,C42 | CAP_5X5.4 | 2 | VT0J101MC054000CE0 | Changzhou Huawei Elec | LCSC | C271407 |  | ¥0.05 | ¥0.01
42 | 560 | R10,R11 | R0603 | 2 | 0603WAF5600T5E | UniOhm | LCSC | C23204 | Yes | ¥0.01 | ¥0.01
43 | 0 | R6,R32,R33 | R0402 | 3 | 0402WGF0000TCE | UniOhm | LCSC | C17168 | Yes | ¥0.01 | ¥0.01
44 | 4.7K | R39,R38,R9,R14,R15,R16,R17,R19,R20,R21,R22,R24,R25,R26,R27,R28,R29,R30,R34,R36,R23,R67 | R0402 | 22 | 0402WGF4701TCE | UniOhm | LCSC | C25900 | Yes | ¥0.01 | ¥0.01
47 | 1uF | C16,C17,C29,C30,C34,C63 | C0402 | 6 | CL05A105KA5NQNC | SAMSUNG | LCSC | C52923 | Yes | ¥0.05 | ¥0.01
49 | SSD1306-128x64-OLED-SPI | WAVESHARE2 | SSD1306-30PIN-POT REVERSED | 1 | ?
50 | PJ-313D_C319112 | AUDIO2 | PHONE-JACK-5P-6.0X12.5-H5.0 | 1 | PJ-313D | XKB Enterprise | LCSC | C319112 |  | ¥0.52 | ¥0.32
51 | W25Q128JVSIQTR | U2 | SOIC-8_L5.3-W5.3-P1.27-LS8.0-BL | 1 | W25Q128JVSIQTR | WINBOND | LCSC | C97521 | Yes | ¥4.61 | ¥3.00
53 | 600Ω | L1 | L0805 | 1 | GZ2012D601TF | Sunlord | LCSC | C1017 | Yes | ¥0.05 | ¥0.03
54 | 39K | R59 | R0603 | 1 | 0603WAF3902T5E | UniOhm | LCSC | C23153 | Yes | ¥0.01 | ¥0.01
55 | STM32F405RGT6 | U20 | LQFP-64_L10.0-W10.0-P0.50-LS12.0-TL | 1 | STM32F405RGT6 | ST | LCSC | C15742
 |  |  |  |  |  |  |  |  | Total | 23.49 | 16.27

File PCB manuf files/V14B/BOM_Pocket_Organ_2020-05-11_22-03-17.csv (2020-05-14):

ID | Name | Designator | Footprint | Quantity | Manufacturer Part | Manufacturer | Supplier | Supplier Part | LCSC Assembly
1 | USB_OTG | P2 | MICRO_USB_C10418 | 1 |  |  | LCSC | C10418
2 | TP4057 | IC2 | SOT-23-6 | 1 | TP4057 | TOPPOWER | LCSC | C12044
3 | 10k | R52 | 0402 | 1 | 0402WGF1002TCE | UniOhm | LCSC | C25744
4 | 10u | C32,C45,C59,C56 | 0402 | 4 | CL05A106MQ5NUNC | SAMSUNG | LCSC | C15525
5 | 100n | C33,C44,C58,C49,C57,C55,C54,C53,C52,C60,C62,C61,C64,C46,C43,C40,C35,C67,C68,C69,C70,C71,C72,C73 | 0402 | 24 | CL05B104KO5NNNC | SAMSUNG | LCSC | C1525
6 | SAM2695 | U8 | QFN48G-0.4-6X6MM | 1
7 | 4.7u | C48 | 0402 | 1 | CL05A475MP5NRNC | SAMSUNG | LCSC | C23733
8 | 47k | R54,R53,R2,R12,R13 | 0402 | 5 | 0402WGF4702TCE | UniOhm | LCSC | C25792
9 | Jumper:SolderJumper_2_Bridged | JP2 | JMP-2-NC-WIRE | 1
10 | 220 | R64,R66,R72,R76,R79,R81,R83,R56,R78,R80,R82,R84,R65,R69,R73,R85,R86 | 0402 | 17 | 0402WGF2200TCE | UniOhm | LCSC | C25091
11 | 1k | R57,R1 | 0402 | 2 | 0402WGF1001TCE | UniOhm | LCSC | C11702
12 | 1 | R47,R48 | 0402 | 2 | 0402WGF100KTCE | UniOhm | LCSC | C25086
13 | 2.2u | C51,C47 | 0603 | 2 | CL05A225MQ5NSNC | SAMSUNG | LCSC | C23630
14 | 1u | C36,C37,C38,C39,C3,C1 | 0402 | 6 | CL05A105KA5NQNC | SAMSUNG | LCSC | C52923
15 | 22 | R5,R7 | R0402 | 2 | 0402WGF220JTCE | UniOhm | LCSC | C25092 | Yes
16 | 19-213/Y2C-CQ2R2L/3T(CY) | LED2-Y | LED0603-R-RD | 1 | 19-213/Y2C-CQ2R2L/3T(CY) | EVERLIGHT | LCSC | C72038 | Yes
17 | AB_PAD2 | U16,U17,U21 | AB_PAD4 | 3
18 | AB_PAD2 | U22,U23,U24 | AB_PAD3 | 3
19 | AB_PAD2 | U25,U26 | AB_PAD5 | 2
20 | 12MHz | X1,X3 | OSC-SMD_4P-L3.2-W2.5-BL | 2 | X322512MSB4SI | YXC | LCSC | C9002 | Yes
21 | Reverse bicolor LED | LED12,LED15,LED16,LED17,LED18,LED19,LED20,LED21,LED22,LED3 | LED-SMD_4PIN-L3.2-W1.25-H1.1-TR-TEMPE | 10 | 23-22B/R7G6C-A30/2A | Everlight | LCSC | C131287
22 | 100K | R35 | R0402 | 1 | 0402WGF1003TCE | UniOhm | LCSC | C25741 | Yes
23 | 20pF | C11,C12 | C0402 | 2 | 0402CG200J500NT | FH | LCSC | C1554 | Yes
24 | SS14 | D4 | SMA_L4.3-W2.6-LS5.2-FD | 1 | SS14 | MDD | LCSC | C2480 | Yes
25 | 10nF | C63,C9,C18,C21 | C0402 | 4 | CL05B103KB5NNNC | SAMSUNG | LCSC | C15195 | Yes
26 | 10K | R31 | R0402 | 1 | 0402WGF1002TCE | UniOhm | LCSC | C25744 | Yes
27 | 4.7nF | C78,C82,C7,C8,C10,C17,C19,C20 | C0402 | 8 | 0402B472K500NT | FH | LCSC | C1538 | Yes
28 | XC6206P332MR | U3 | SOT-23-3_L2.9-W1.6-P1.90-LS2.8-BR | 1 | XC6206P332MR | TOREX | LCSC | C5446 | Yes
29 | A2001WR-S-2P | BAT2 | A2001WR-S-2P | 1 | A2001WR-S-2P | Changjiang Connectors | LCSC | C225233
30 | 2.2uF | C2,C79 | C0603 | 2 | CL10A225KO8NNNC | SAMSUNG | LCSC | C23630 | Yes
31 | 200K | R3,R4 | R0603 | 2 | 0603WAF2003T5E | UniOhm | LCSC | C25811 | Yes
32 | 74HC595A | SR3,SR4 | SOIC-16_150MIL | 2 | 74HC595D,118 | Nexperia | LCSC | C5947
33 | SK-12D02-VG3 | SW2 | DIP-8.6X4.4 | 1 | SK-12D02-VG3 | Rectangular Connectors - Contacts | LCSC | C136723
34 | SOLDER-BRIDGE | JP1,JP4,JP5,JP7,JP8,JP10,JP11,JP13,JP3,JP9,JP12,JP6,JP14,JP15,JP16,JP17 | JUMPER_SOLDER_1X2 | 16 | SOLDER-BRIDGE
35 | 4.7uF | C50 | C0402 | 1 | CL05A475MP5NRNC | SAMSUNG | LCSC | C23733 | Yes
36 | EVQ22705R | DB20,DB21,DB22,DB23 | PAD_3 | 4
37 | 1K | R8,R9 | R0402 | 2 | 0402WGF1001TCE | UniOhm | LCSC | C11702 | Yes
38 | 1K | RN1,RN2,RN5,RN6,RN7,RN8,RN9,RN12,RN10,RN11,RN4 | RES-ARRAY-SMD_0402-8P-L2.0-W1.0-BL | 11 | 4D02WGJ0102TCE | UniOhm | LCSC | C25726 | Yes
39 | 19-217/GHC-YR1S2/3T | LED4-G | LED0603-R-RD | 1 | 19-217/GHC-YR1S2/3T | EVERLIGHT | LCSC | C72043 | Yes
40 | TTY6955 | U19,U1,U9,U12 | SSOP-28_L9.9-W3.9-P0.64-LS6.0-BL | 4 | TTY6955 | TONTEK | LCSC | C172713 | Yes
41 | 22nF | C22,C23,C65,C66 | C0402 | 4 | 0402B223K500NT | FH | LCSC | C1532 | Yes
42 | SHARP | U18,U10,U11 | CAPA12 | 3
43 | SHIFT | U4 | CAPA12 | 1
44 | MINOR | U7,U13 | CAPA12 | 2
45 | 3RD | U6 | CAPA12 | 1
46 | 5TH | U5 | CAPA12 | 1
47 | 7TH | U14 | CAPA12 | 1
48 | KXTJ3-1057 | U15 | LGA-12_L2.0-W2.0-P0.50-BL | 1 | KXTJ3-1057 | ROHM Semicon | LCSC | C442603 | Yes
49 | 10pF | C4,C5,C6,C13,C14,C15,C16,C24,C25,C26,C27,C28,C29,C30,C31,C34,C80,C81,C77 | C0402 | 19 | CL05C100JB5NNNC | SAMSUNG | LCSC | C32949 | Yes
50 | KT-0603R | LED1 | LED0603-FD | 1 | KT-0603R | KENTO | LCSC | C2286 | Yes
51 | 100uF | C41,C42 | CAP_5X5.4 | 2 | VT0J101MC054000CE0 | Changzhou Huawei Elec | LCSC | C271407
52 | 560 | R10,R11 | R0603 | 2 | 0603WAF5600T5E | UniOhm | LCSC | C23204 | Yes
53 | 2X4 | P3 | 2X4 | 1 | IDC Box 2X4 2.54MM | BOOMELE | LCSC | C9135
54 | 0 | R6,R32,R33,R34 | R0402 | 4 | 0402WGF0000TCE | UniOhm | LCSC | C17168 | Yes
55 | 4.7K | R39,R38 | R0402 | 2 | 0402WGF4701TCE | UniOhm | LCSC | C25900 | Yes
56 | SSD1306-128x64-OLED-SPI | WAVESHARE2 | SSD1306-30PIN-POT REVERSED | 1 | ?
57 | PJ-313D_C319112 | AUDIO2 | PHONE-JACK-5P-6.0X12.5-H5.0 | 1 | PJ-313D | XKB Enterprise | LCSC | C319112
58 | W25Q128JVSIQTR | U2 | SOIC-8_L5.3-W5.3-P1.27-LS8.0-BL | 1 | W25Q128JVSIQTR | WINBOND | LCSC | C97521 | Yes
59 | K2-1107ST-A4SW-06 | SW1,SW3,SW4,SW5 | KEY-SMD_L6.2-W3.6-LS8.0-TEMPE | 4 | K2-1107ST-A4SW-06 | Rectangular Connectors - Contacts | LCSC | C118141
60 | Slide Key 4 pads | SL1 | CAPA_SLIDER_4_50B | 1 |  | Generic Components
61 | Slide Key 4 pads | SL2,SL3 | CAPA_SLIDER_4_40B | 2 |  | Generic Components
62 | 600Ω | L1 | L0805 | 1 | GZ2012D601TF | Sunlord | LCSC | C1017 | Yes
63 | STM32F405RGT6 | U20 | LQFP-64_L10.0-W10.0-P0.50-LS12.0-TL | 1 | STM32F405RGT6 | ST | LCSC | C15742

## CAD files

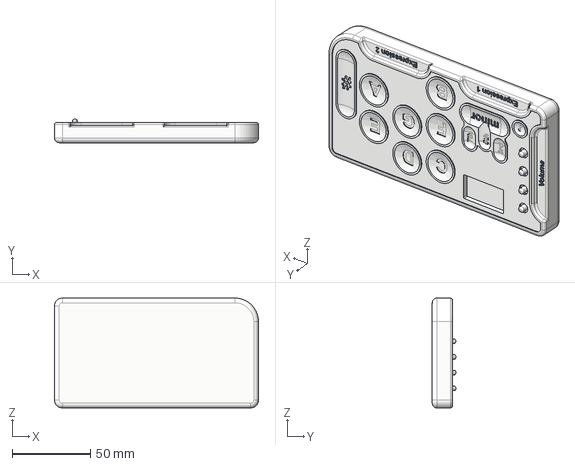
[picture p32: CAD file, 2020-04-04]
3D models/V11 mock-up/Pocket organ V11 mock-up v18 - with engraving, 0.5mm depression for front plate.step
130.0 x 15.0 x 70.0 mm

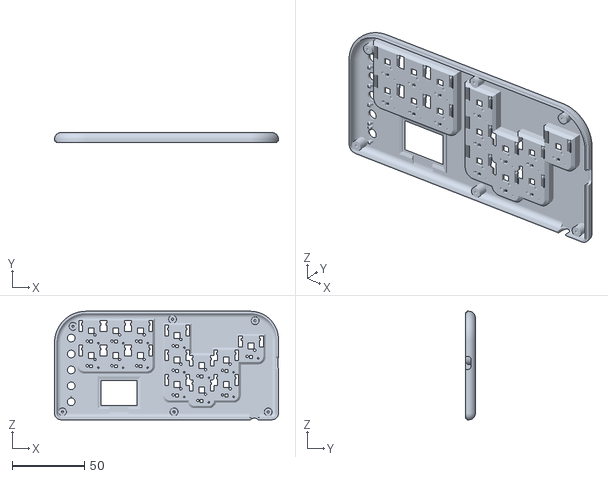
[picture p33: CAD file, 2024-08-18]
3D models/V26-28/top.stl
154.6 x 6.80 x 74.9

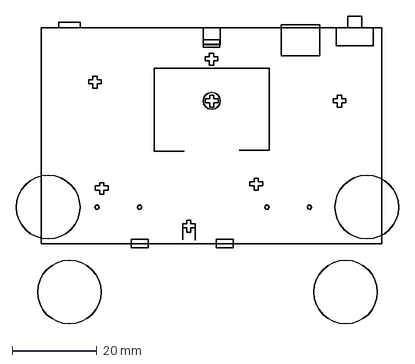
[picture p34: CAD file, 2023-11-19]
PCB manuf files/PCB outline.dxf
90.0 x 72.5 mm

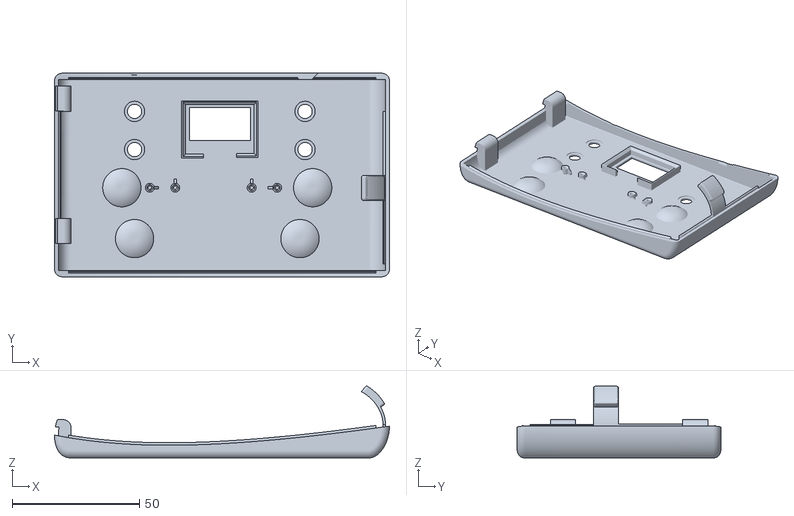
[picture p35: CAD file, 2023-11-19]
PCB manuf files/V21/Upper shell.stl
131.6 x 80.0 x 28.3

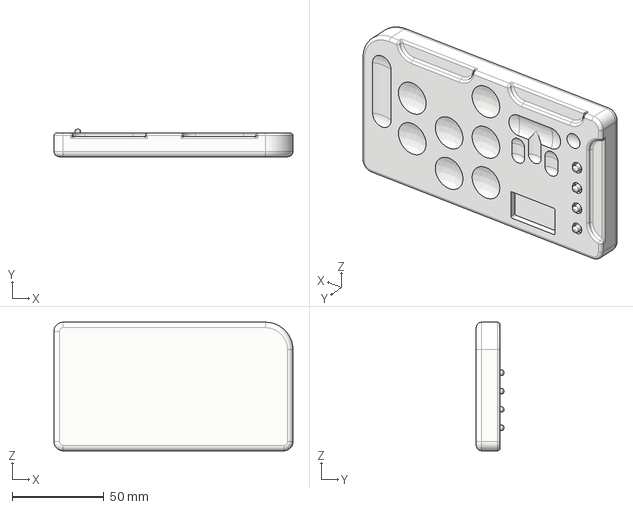
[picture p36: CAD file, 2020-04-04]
3D models/V11 mock-up/Pocket organ V11 mock-up v18 - no engraving, no depression for front plate.step
130.0 x 15.0 x 70.0 mm

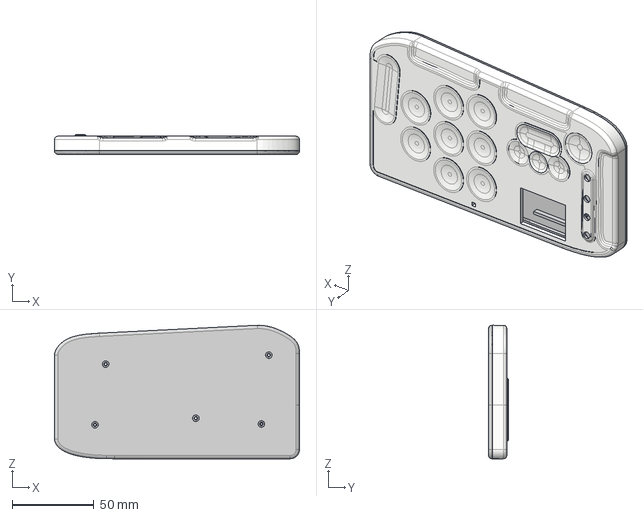
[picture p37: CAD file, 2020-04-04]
3D models/V11 prototype/Pocket organ V11 enclosure v21.step
149.4 x 12.1 x 81.4 mm

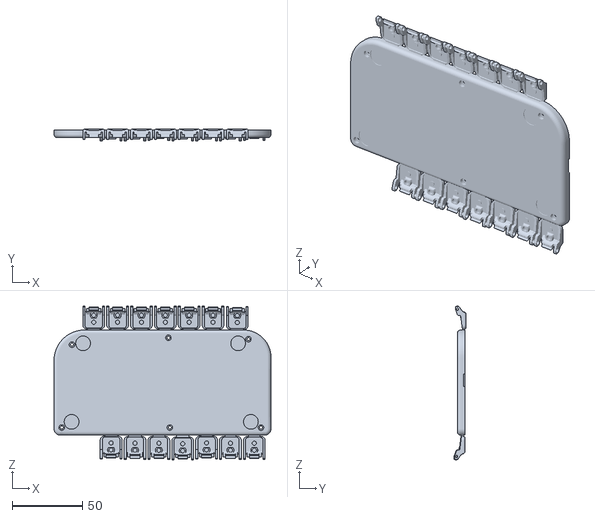
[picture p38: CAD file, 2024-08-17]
3D models/V26/bottom.stl
154.6 x 8.30 x 109.6

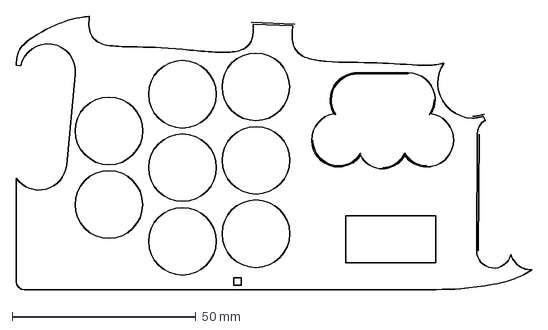
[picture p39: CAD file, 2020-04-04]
3D models/V11 prototype/top skin v22.dxf
140.3 x 74.4 mm

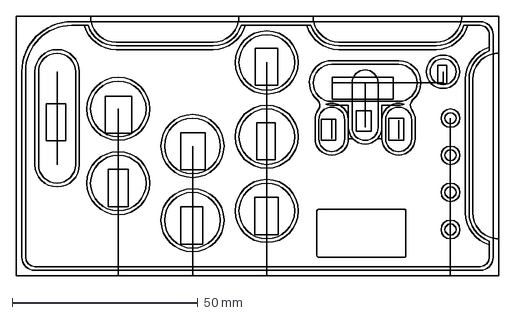
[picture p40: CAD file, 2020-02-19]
3D models/V11 mock-up/cover plate design.dxf
130.0 x 70.0 mm

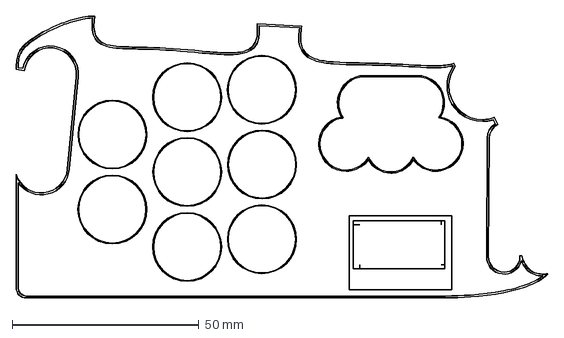
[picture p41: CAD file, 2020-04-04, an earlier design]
3D models/V11 prototype/top skin v21.dxf
142.1 x 75.4 mm

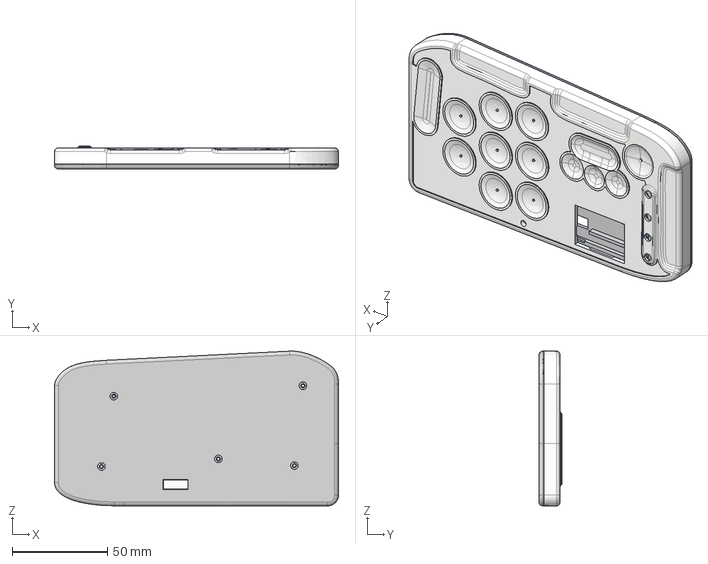
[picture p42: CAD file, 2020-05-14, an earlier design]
3D models/V12/Pocket organ V11 enclosure v28.step
149.4 x 12.1 x 81.4 mm

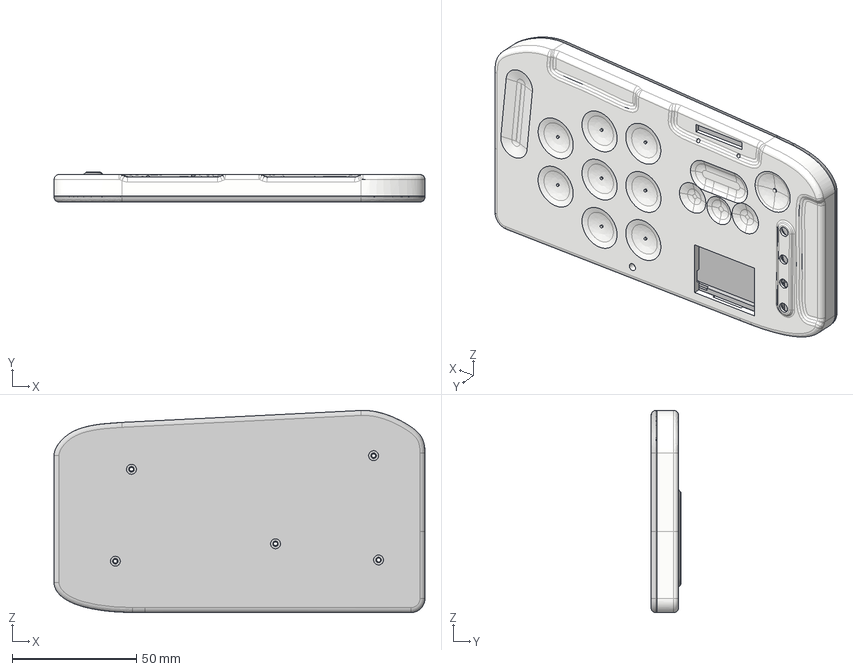
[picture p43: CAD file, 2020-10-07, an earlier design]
3D models/V15/Pocket organ V15 enclosure v2.step
149.4 x 12.1 x 81.4 mm

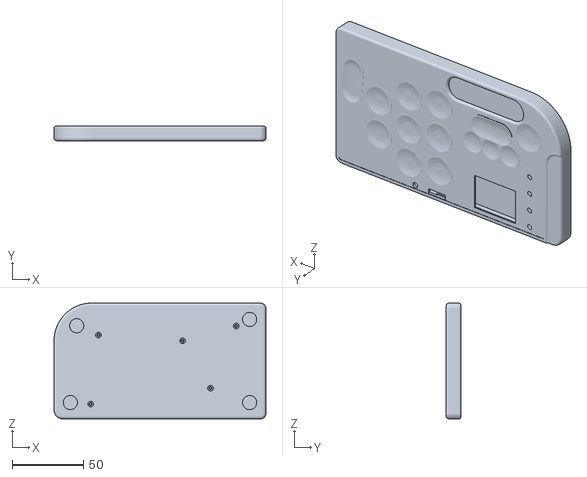
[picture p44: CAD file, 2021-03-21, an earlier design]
3D models/V17/Pocket organ V17 enclosure v6.stl
149.0 x 10.3 x 81.5

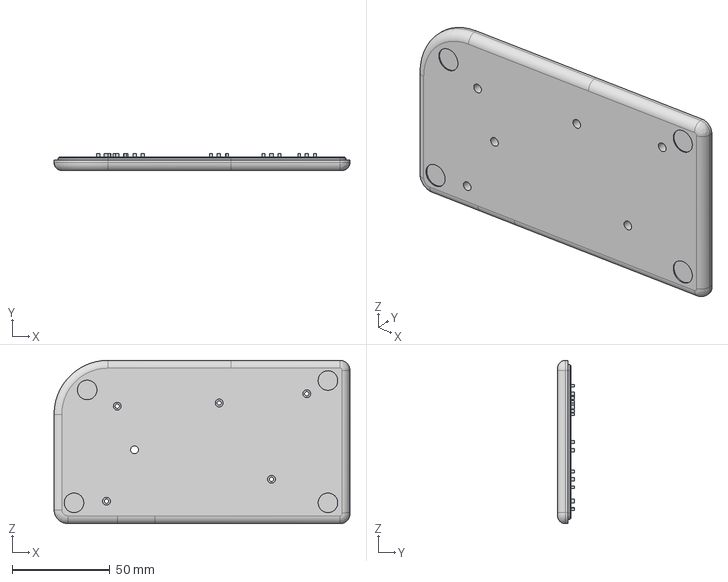
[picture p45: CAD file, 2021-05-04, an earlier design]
3D models/V18/Pocket organ V18 V8 bot.step
151.1 x 8.60 x 83.4 mm

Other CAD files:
3D models/V11 mock-up/Pocket organ V11 mock-up v18 - partial engraving, 0.5mm depression for front plate.step
3D models/V11/Pocket organ V11 mock-up v14 - with engraved texd.step
3D models/V19/Pocket organ V19 for tool quote.step
3D models/V17/Bottom v7.step
3D models/V17/Enclosure V17 v7.step
3D models/V17/Pocket_Organ_V17_2021-03-17.dxf
3D models/V17/top v7.step
3D models/V18/Pocket organ V18 enclosure (redone) v9.f3d
3D models/V18/Pocket organ V18 v8 top.step
3D models/V18/front panel.dxf
3D models/V19/Pocket organ V19 v2 for printing.f3d
3D models/V19/Pocket organ V19B Bottom.f3d
3D models/V19/Pocket organ V19B Bottom.stl
3D models/V19/Pocket organ V19B Top.stl
3D models/V19/V19 bottom.step
3D models/V19/V19 top.step
3D models/V19/V19B bottom.step
3D models/V19/V19B top.step
3D models/V19/top cover.dxf
3D models/V20/Pocket organ V20 bottom.step
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

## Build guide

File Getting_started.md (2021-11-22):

Getting started

# Turning on

# Playing your first song

# Where to find more songs 

## 中文歌剧列表 Chinese songs 

* 大海 - 张雨生 https://jitaq.com/post/5ca885e08a7fa.html
* 再回首 - 姜育恒 http://www.tan8.com/guitarChords-104278.html
* 同桌的你 - 老狼 http://www.tan8.com/guitarChords-90516.html
* 大约在冬季 - 齐秦 https://www.docin.com/p-1753241454.html
* 平凡之路 - 朴树 http://www.tan8.com/guitarChords-88116.html
* 爱情转移 - 陈奕迅 http://www.tan8.com/guitarChords-98280.html
* 水手 - 郑智化 http://www.798com.com/article-41917-1.html
* 把我的悲伤留给自己 - 陈升 http://www.tan8.com/guitarChords-98989.html
* 青春修炼手册 - TFBOY http://www.tan8.com/guitarChords-93833.html

## 怎么搜？ How to searh -- Chinese 

* http://baidu.com 搜歌曲名称加“和弦”
* 使用专用歌曲和弦网页：
* * https://yoopu.me/
* * http://www.tan8.com/ 
* 找不到就可以搜图片，快速判断好坏
* 百度找不到也可以尝试http://bing.com
* 不要看“简化谱”，“吉他谱”，“五线谱”等

## 怎么判断好坏 what to look for -- Chinese 
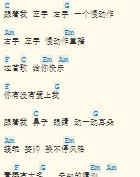
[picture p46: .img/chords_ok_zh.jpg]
simple chords, easy to read
* 很好 
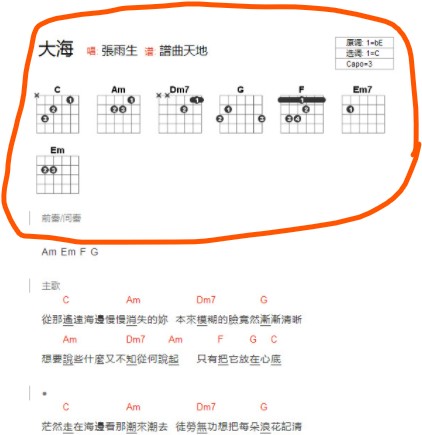
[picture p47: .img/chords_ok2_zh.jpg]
same, with guitar chord shapes on top
* 不影响： 歌词之上有吉他的和弦图 
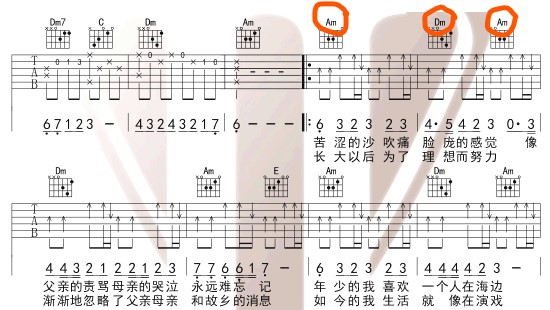
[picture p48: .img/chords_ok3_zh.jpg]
guitar tabs + chords
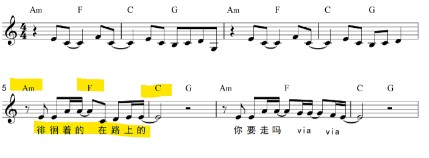
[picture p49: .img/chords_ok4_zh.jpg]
partition + chords
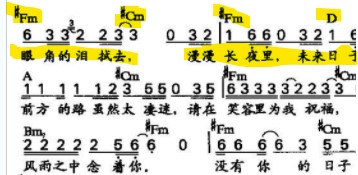
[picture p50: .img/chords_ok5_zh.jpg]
simplified partition + chords
* 可以接受：显示和弦名称的吉他谱或五线谱。虽然不是很方便，但是还是可以用。   

新手建议不要选择太复杂的和弦谱。同一首歌可以写成不同难度的和弦谱，如果觉得比较难，建议继续搜搜。
* 首次体验：只有大调（单个字母）的和弦： C、D、E、F、G、A、B
* 够简单：某些和弦是小调，如：Cm、Dm、Em等。大部分歌曲和弦谱是这样。
* 稍微难一点：还有一些7号和弦：D7、Cm7等。（不熟悉的话可以忽略7号，直接谈D，Cm）
* 高级专家级别，新手请换一份谱子：涵盖各种奇奇怪怪的和弦，如：C/G，Dsus2，E#，Fm4等

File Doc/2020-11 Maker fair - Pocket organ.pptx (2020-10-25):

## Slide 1

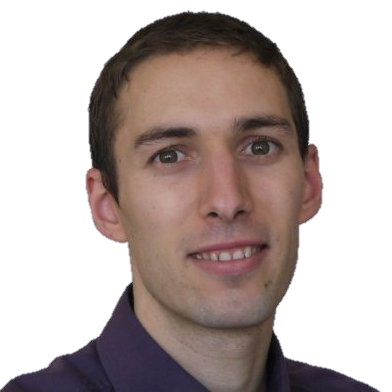
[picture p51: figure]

Pocket organ 口袋琴

Very few instruments are actually modern. Most of them have centuries-old user interfaces, constrained by the limits of woodworking and the need to produce sound. What if we were to design an instrument today? I want mine to fit in my pocket, be easy and fun to learn, and be expressive, cheap, open source, and easily hackable.
实际上当下很少有乐器可以被认为是现代的，受限于几百年前的制作工艺和材料，大部分乐器的用户界面都有着数百年的历史。如果我们按现代的技术与人体工程设计一款乐器，它会是什么样的？我希望它能轻松地塞在衣服口袋里，易学好用，有充分的表现力，便宜，开源，并且有容易更改的设计代码。

Maker Name: Thomas TEMPE 唐沛

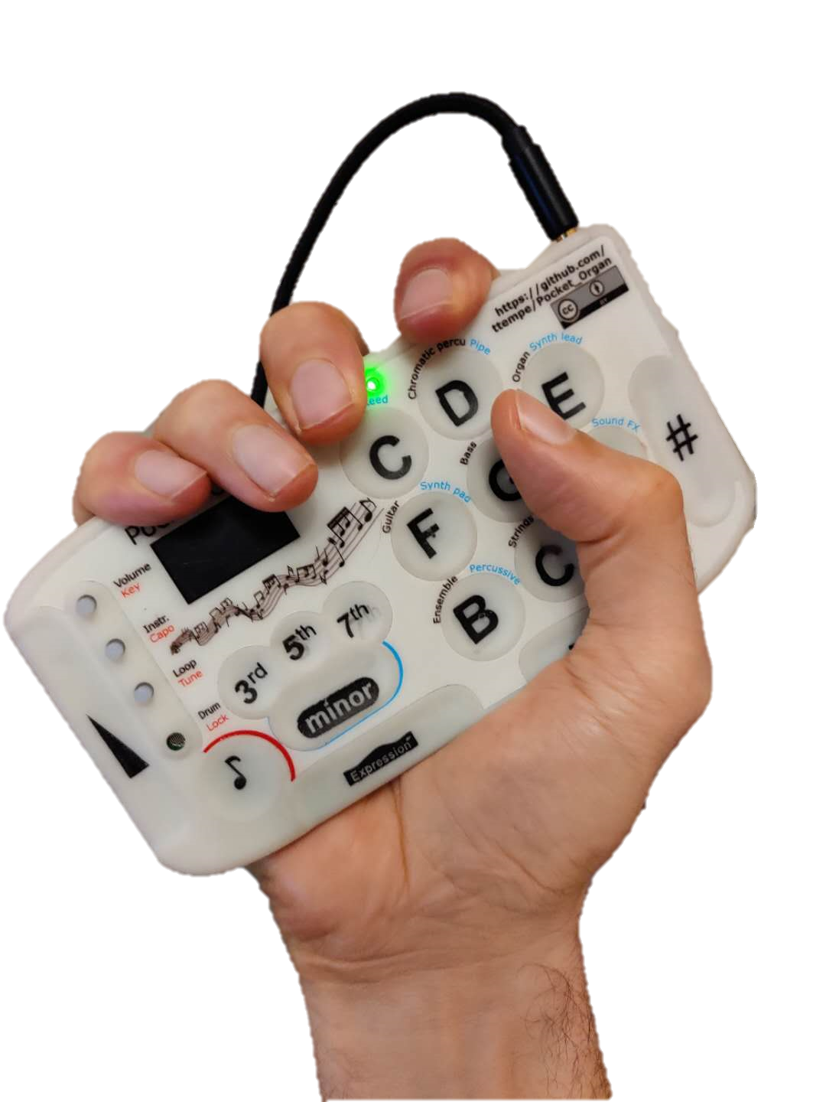
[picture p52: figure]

Project Picture

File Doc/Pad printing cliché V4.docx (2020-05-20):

minor

Expression

Thomas

TEMPÉ

唐沛

C D E F

G A B # ♪

7th 5th 3rd

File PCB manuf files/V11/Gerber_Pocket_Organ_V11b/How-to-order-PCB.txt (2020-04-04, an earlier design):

How to Order PCB

Please refer to:
https://docs.easyeda.com/en/PCB/Order-PCB

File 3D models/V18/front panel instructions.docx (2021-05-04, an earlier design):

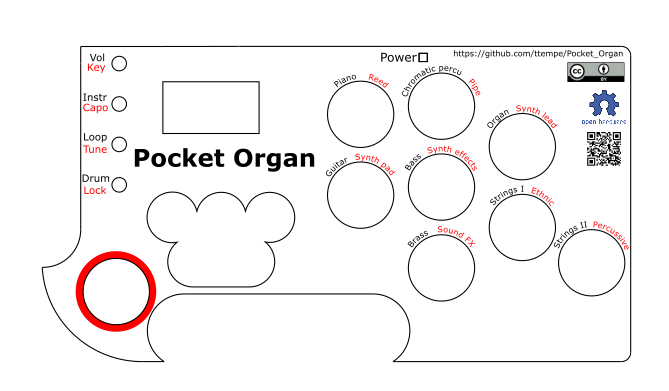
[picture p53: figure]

白色，带背胶

透明无胶

打孔

打孔

打孔

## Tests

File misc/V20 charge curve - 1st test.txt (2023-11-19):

101,00h01m41s,3.584399,5.028552
112,00h01m52s,3.586011,5.047888
122,00h02m02s,3.626294,5.055945
132,00h02m12s,3.623071,5.093005
142,00h02m22s,3.624683,5.080115
152,00h02m32s,3.65852,5.015662
162,00h02m42s,3.650464,5.073669
173,00h02m53s,3.656909,5.028552
183,00h03m03s,3.650464,5.055945
193,00h03m13s,3.674634,5.067224
203,00h03m23s,3.681079,5.067224
213,00h03m33s,3.708472,5.033386
223,00h03m43s,3.687524,5.073669
234,00h03m54s,3.687524,5.036609
244,00h04m04s,3.71824,5.08656
254,00h04m14s,3.708472,5.041443
264,00h04m24s,3.719852,5.080115
274,00h04m34s,3.710083,5.052722
285,00h04m45s,3.726297,5.018884
295,00h04m55s,3.732742,5.052722
305,00h05m05s,3.72952,5.070446
315,00h05m15s,3.752078,5.08656
325,00h05m25s,3.75369,5.084949
336,00h05m36s,3.744022,5.041443
346,00h05m46s,3.745633,5.054333
356,00h05m56s,3.75369,5.041443
366,00h06m06s,3.752078,5.047888
376,00h06m16s,3.779471,5.072058
386,00h06m26s,3.761746,5.080115
397,00h06m37s,3.781082,5.080115
407,00h06m47s,3.776248,5.052722
417,00h06m57s,3.81492,5.08656
427,00h07m07s,3.803641,5.112341
437,00h07m17s,3.777859,5.041443
448,00h07m28s,3.821365,5.076892
458,00h07m38s,3.795584,5.052722
468,00h07m48s,3.821365,5.093005
478,00h07m58s,3.808475,5.112341
488,00h08m08s,3.793973,5.08656
498,00h08m18s,3.821365,5.118786
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

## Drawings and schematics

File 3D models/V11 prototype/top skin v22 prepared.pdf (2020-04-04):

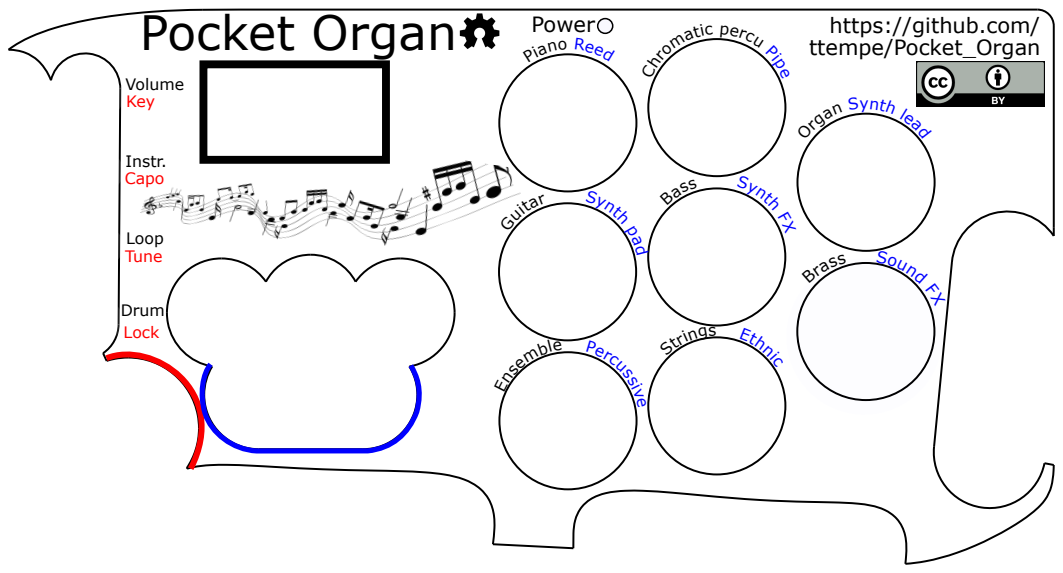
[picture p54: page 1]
Power Piano Reed; Bass Synth; Ensemble Percussive; Guitar Synth; pad; Strings Ethnic; Volume; Instr.; Key; Tune; Loop; Lock; Capo; Drum; Pocket Organ; https://github.com/; ttempe/Pocket_Organ

Chromatic percu Pipe

Organ Synth lead

Brass Sound FX

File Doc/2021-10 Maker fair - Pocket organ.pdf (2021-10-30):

# Pocket organ 口袋琴

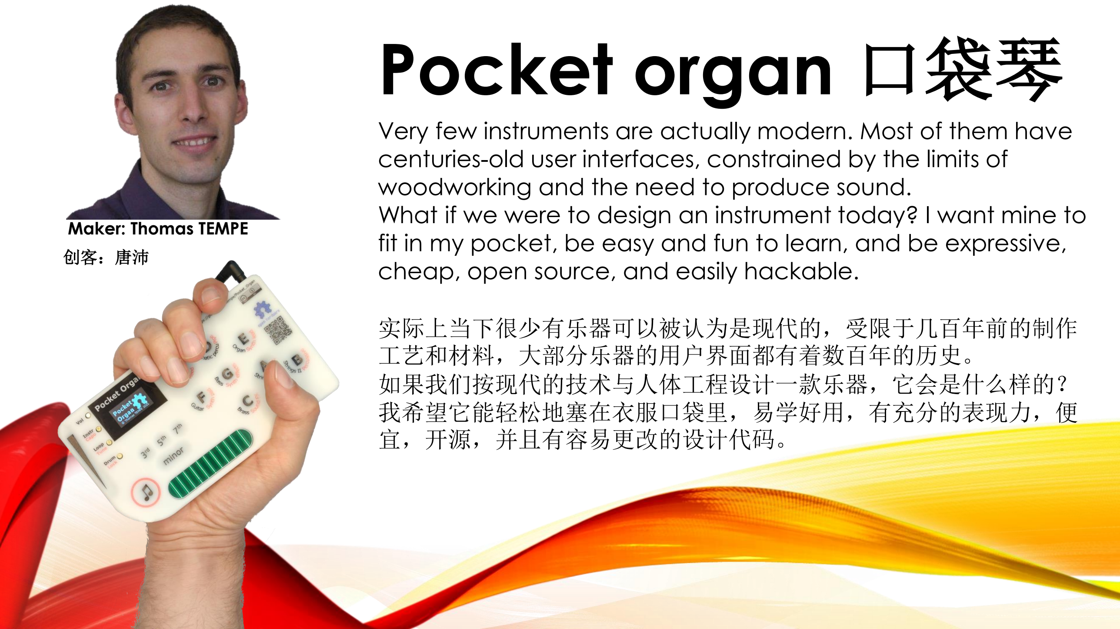
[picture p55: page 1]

Very few instruments are actually modern. Most of them have centuries-old user interfaces, constrained by the limits of woodworking and the need to produce sound.
What if we were to design an instrument today? I want mine to fit in my pocket, be easy and fun to learn, and be expressive, cheap, open source, and easily hackable.

实际上当下很少有乐器可以被认为是现代的，受限于几百年前的制作 工艺和材料，大部分乐器的用户界面都有着数百年的历史。 如果我们按现代的技术与人体工程设计一款乐器，它会是什么样的？ 我希望它能轻松地塞在衣服口袋里，易学好用，有充分的表现力，便 宜，开源，并且有容易更改的设计代码。

Maker: Thomas TEMPE
创客：唐沛

## MUSICAL INSTRUMENTS DESIRABLE ATTRIBUTES

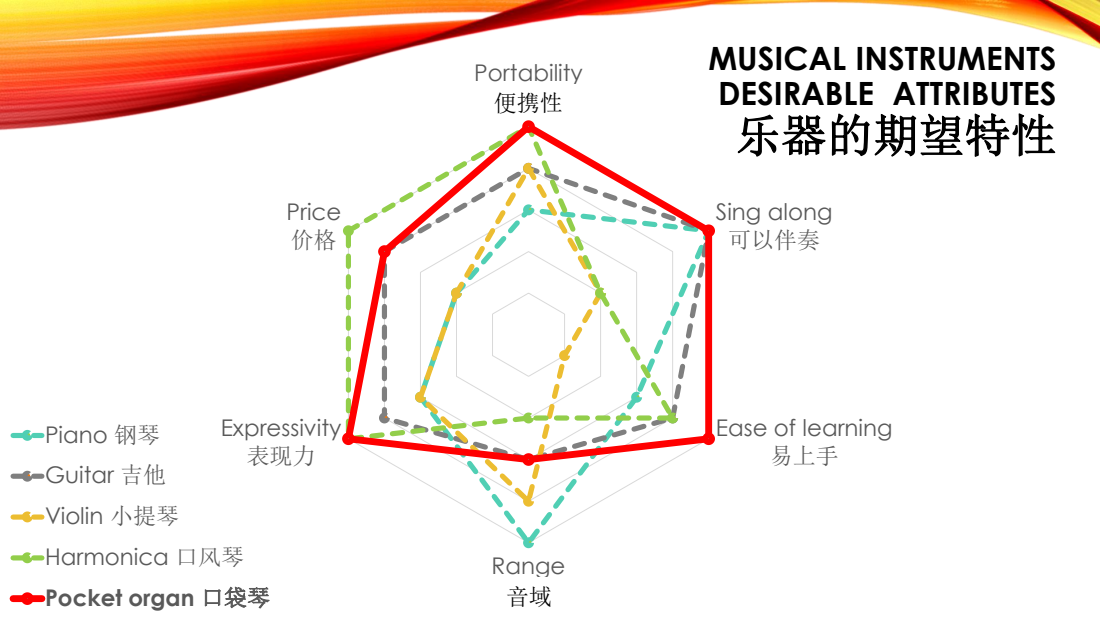
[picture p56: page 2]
Portability 移动性; Sing along 可以伴奏; Range 范围; Expressivity 表现力; Price 价格; 便携性; 乐器的期望特性

Piano 钢琴
Guitar 吉他
Violin 小提琴
Harmonica 口风琴
Pocket organ 口袋琴

Ease of learning
易上手

# INSTRUMENT LAYOUT

# 乐器的样子

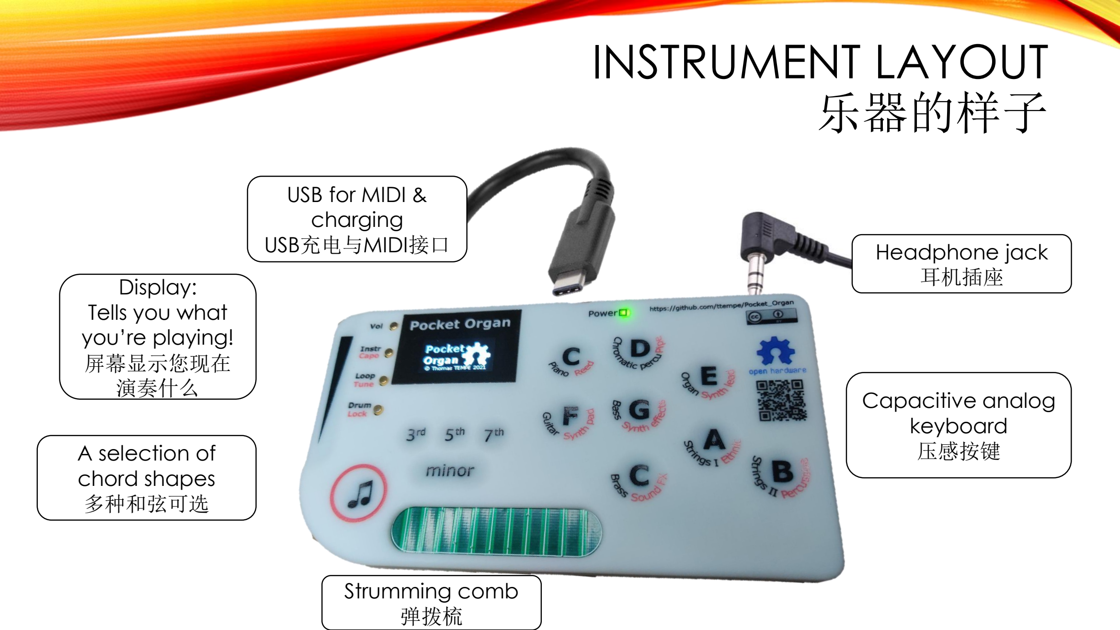
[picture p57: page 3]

Capacitive analog
keyboard
A selection of | 压感按键
chord shapes
多种和弦可选

Headphone jack
Display: | 耳机插座

Tells you what
you’re playing!
屏幕显示您现在
演奏什么

USB for MIDI &
charging
USB充电与MIDI接口

Strumming comb
弹拨梳

# EASILY LOOKUP GUITAR CHORDS

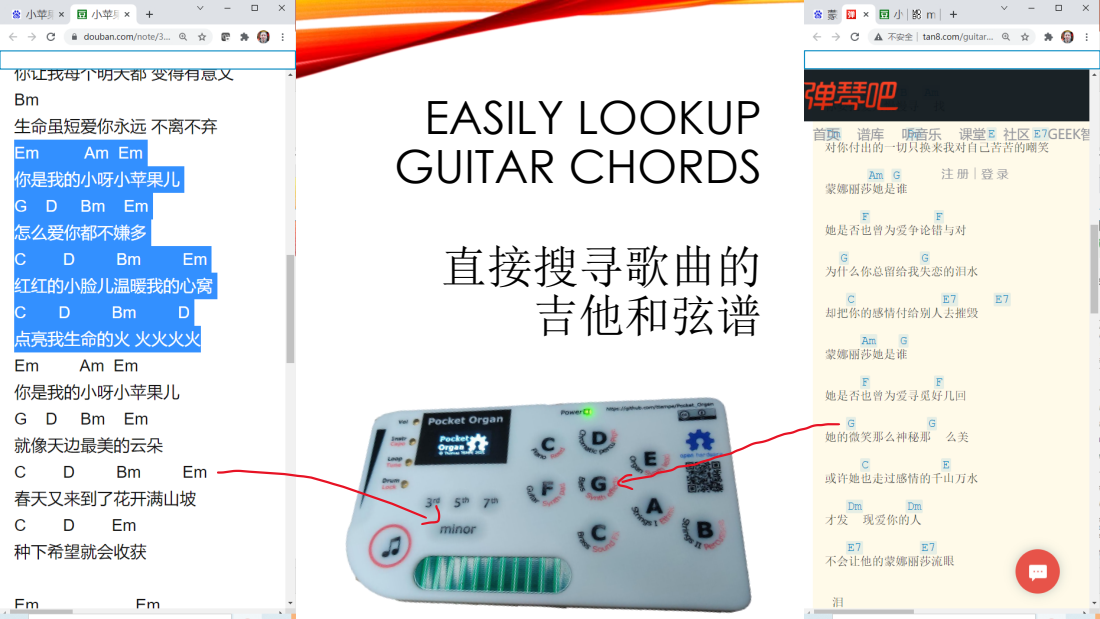
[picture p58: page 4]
直接搜寻歌曲的 吉他和弦谱

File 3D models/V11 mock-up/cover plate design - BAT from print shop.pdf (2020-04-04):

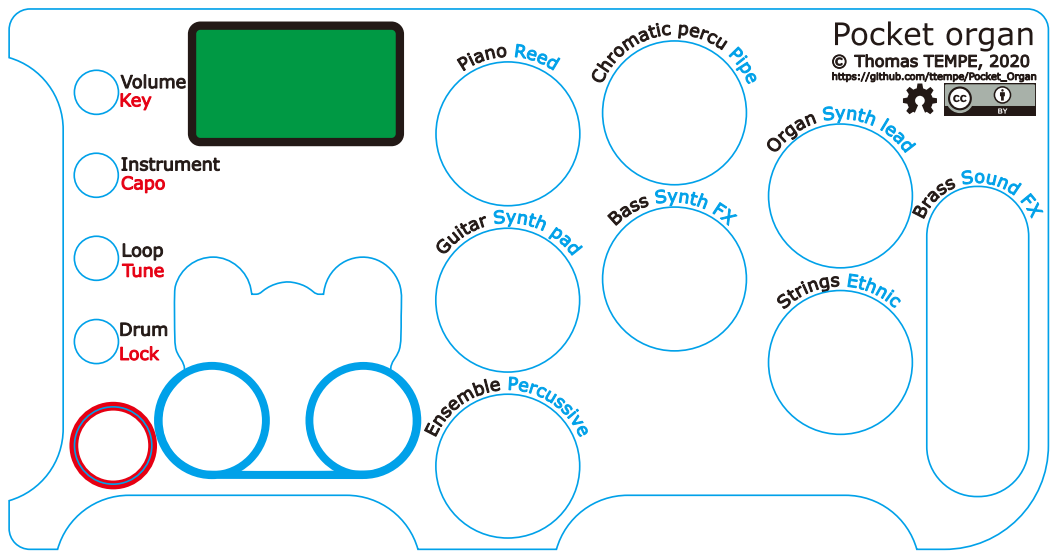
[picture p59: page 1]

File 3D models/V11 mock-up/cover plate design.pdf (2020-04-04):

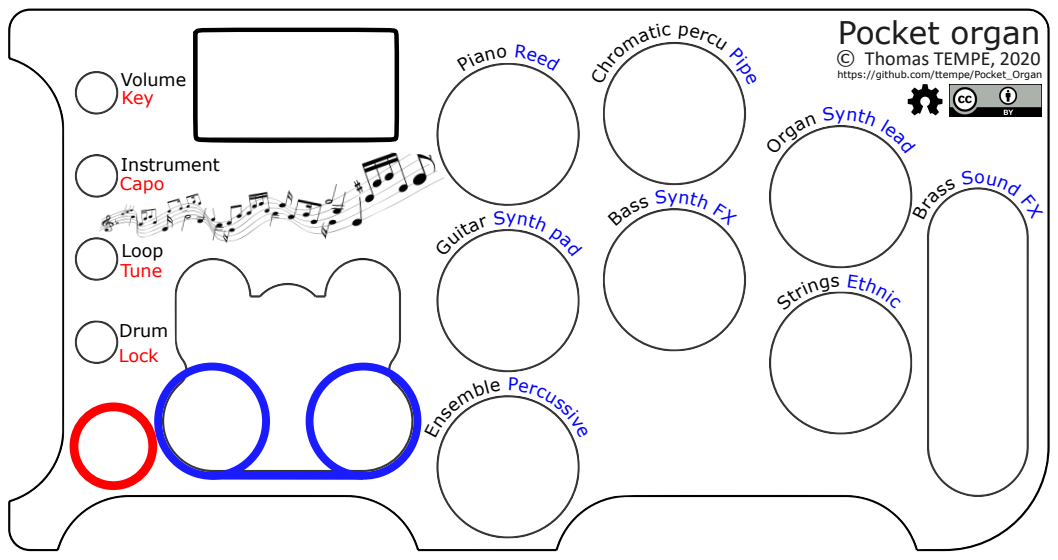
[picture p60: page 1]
Volume; Instrument; Key; Tune; Loop; Lock; Capo; Drum; Pia; Reed; Organ; n th lead; Chromati; p e rcu Pipe; Bass; Ensembl; P e rcussive; Guitar; y n th pad; Brass; Strin; Ethnic

Pocket organ © Thomas TEMPE, 2020

https://github.com/ttempe/Pocket_Organ

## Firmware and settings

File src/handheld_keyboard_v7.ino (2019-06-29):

/////////////////
//This version goes on:
// * v7 & V8 & V9 boards (2019-05)

/*TODO:
 * chords: play all chords from the same octave (keep the Si from sounding higher than the Do)
 * Change the 7th based on the selected key
 * Change the degree of the fundamental based on the selected key (eg: minor keys...)
 * Tune
 * enable Midi output
 * more expression channels
 * use one of the expression channels to add more notes from that chord (lower/higher octaves)
 * bend only the top key in that loop?
 * Use different channels for melody and chords?
 * Make each note of a chord play at different pressure levels?
 * Add expression to melody mode
 * Add display
 * Rythm box
 * Calculate (and display on startup) the time spent playing since you got the instrument
 */




//////////////////////////////////////////////////////////////////////////////////////////////
#include <EEPROM.h>
#ifdef OUT_USB
#include "MIDIUSB.h"
#endif
#include "handheld_keyboard.h"
#include "Support.h"
#include "piano.h"
#include "tests.h"



const char keybExpression[7][2] = //Expression1, Expression2
{{1, 2}, //Do
 {0, 2},  //Re
 {0, 1},  //Mi
 {4, 5},  //Fa
 {3, 5},  //Sol
 {3, 4},  //La
 {4, 5}   //Si
 };

char volume = 60;
char transpose = 60;
Polyphony P;
Piano myPiano(&P);



void chordPlayGuitar(char degree){
  //Determine which chord shape the user wants to play, based on the digital buttons in use
  char scale, n; //M, m, 7, m7, 9, sus4, sus2
  char transp;
  scale = (not digitalRead(DB[B_MIN])) + 2*(not digitalRead(DB[B_7]));
  //Memo: static char guitarChords[7][7][6] = //scale, degree*7, string*6
  transp = not digitalRead(DB[B_SHARP]);
  for (char s=0; s<6; s++){
    n = guitarChords[scale][degree][5-s];
    if (n>-1 and n<64){
      P.playNote(n+transpose+transp+guitarStrings[s]-60);
    }
  }
}

///////////////////////////////////////////////
//Setup
void setup() {
  Serial.begin(115200);
  for (char i=0; i<NB_DB; i++){
    pinMode( DB[i], INPUT_PULLUP); //Mode switch
  }
  pinMode( SR_DATA, OUTPUT);
  pinMode( SR_CLK, OUTPUT);
  SR_blank();
  //analogReference(EXTERNAL);
#ifdef OUT_SERIAL
  delay(500);
  MIDI_SERIAL.begin(31250);
#endif
  char v = EEPROM.read(E_VOLUME);
  if (v){
    volume = v;
  }
  setMidiControl(MIDI_VOLUME, volume, 0);

  
  //setMidiControl(MIDI_RELEASE, 127);
  //setMidiControl(MIDI_EXPRESSION, 127);//Max keyboard xpression, for debugging
  setMidiInstr(22, 0); //1=Piano; 22=accordion; 25=nylon guitar
}

///////////////////////////////////////////////
//Loop

void loopB_Instr_Transpose(){
  int p1, p2;

  //Instrument change
  do {
    p1 = AB::get_keypad_press(true);
    if (p1>-1){
      do {
        if (digitalRead(DB[B_TRANSP])){
          setMidiInstr(p1*8, 0);
          return;
        }
        p2 = AB::get_keypad_press(false);
      } while (p2 == -1);
      setMidiInstr(p1*8+p2, 0);
    }
    
    //Transposition
    if (not digitalRead(DB[B_PLUS]) and transpose<96){
      transpose++;
      delay(100);
      do {} while (not(digitalRead(DB[B_PLUS])));
    }
    if (not digitalRead(DB[B_MINUS]) and transpose>24){
      transpose--;
      delay(100);
      do {} while (not(digitalRead(DB[B_MINUS])));
    }
    if (not digitalRead(DB[B_ZERO])){
      transpose=60;
      delay(100);
      do {} while (not(digitalRead(DB[B_ZERO])));
    }    
  } while (not digitalRead(DB[B_TRANSP]));
}

void loopB_Volume(){
  do {
    if (not digitalRead(DB[B_PLUS]) and volume<110){
      volume+=5;
      delay(100);
      do {} while (not(digitalRead(DB[B_PLUS])));
    }
    if (not digitalRead(DB[B_MINUS]) and volume>10){
      volume-=5;
      delay(100);
      do {} while (not(digitalRead(DB[B_MINUS])));
    }
    if (not digitalRead(DB[B_ZERO])){
      volume = 60;
      delay(100);
      do {} while (not(digitalRead(DB[B_ZERO])));
    }
    if (not digitalRead(DB[B_INSTR]) and not digitalRead(DB[B_LOOP])){
      digitalWrite(LED_BUILTIN, HIGH);
      do {delay(100);} while ((not digitalRead(DB[B_INSTR])) or (not digitalRead(DB[B_LOOP]))or (not digitalRead(DB[B_VOL])));//wait till all 3 keys are released
      AB::calibrate();
      digitalWrite(LED_BUILTIN, LOW);
    }
  } while (not digitalRead(DB[B_RYTHM]));
  EEPROM.update(E_VOLUME, volume);
  setMidiControl(MIDI_VOLUME, volume, 0);
}

void loopB_Rythm(){
}

void loopB_Melody(){
  char m[NB_AB], playing=-1, playingNote, b_melody, b_melody_lock, locked, was_locked;
  
  //First read initial state of all analog buttons. Ignore them until they are released.
  for (int i=0; i<NB_AB; i++){
    m[i] = AB::readVel(i);
  }
  digitalWrite(LED_BUILTIN, HIGH);
  do { //Loop: play newly pressed buttons

    //handle analog buttons
    for (int i=0; i<NB_AB; i++){
      char v= AB::readVel(i);
      if (m[i] and not v){ //Initially pressed button was released. Stop ignoring it.
        m[i]=0;
      } else if ((not m[i]) and v and playing==-1){//Start playing one note
        playing = i;
        playingNote = transpose+(not digitalRead(DB[B_SHARP]))+AB::degree(playing)+(not digitalRead(DB[B_PLUS]))*12-(not digitalRead(DB[B_MINUS]))*12;
        noteOn(playingNote, 96,0);
        SR_one(i);
      } else if (not v and playing == i) { //stop playing that note
        noteOff(playingNote, 0); 
        playing = -1;
        SR_blank();   
      }
    m[i] = v;
    }
    #ifdef OUT_USB
    MidiUSB.flush();
    #endif

    //handle the lock/unlock buttons
    b_melody_lock = digitalRead(DB[B_MELODY_LOCK]);
    b_melody = digitalRead(DB[B_MELODY]);
    if (locked and not b_melody and not was_locked){ //release lock
      delay(100); //wait past rebound
      do {} while (not digitalRead(DB[B_MELODY])); //wait for button release
      locked = 0;
    } else if (not locked and not b_melody_lock and not b_melody){ //lock
      delay(100); //wait past rebound
      do {} while (not digitalRead(DB[B_MELODY_LOCK]));//wait for lock button release
      locked = 1;
      was_locked = 1;
    } else if (locked and b_melody) { //"Melody" button was released, allow to unlock on next press
      was_locked = 0;
    }

  } while (not b_melody or locked);
  digitalWrite(LED_BUILTIN, LOW);
  if (playing != -1){
    noteOff(playingNote, 0);
  }
}

void loopB_Chord(int b, int velocity){
  static int effect1, effect1_old, effect2, effect2_old, velocity_old;

  //collect initial values, and start playing immediately
  //chordPlayGuitar(b);
  myPiano.chordPlay(b, transpose);
  SR_one(b);

  //Update the play
  do {
    //Expression
    effect1 = AB::readVel(keybExpression[b][0]);
    effect2 = AB::readVel(keybExpression[b][1]);
    if (abs(effect1-effect1_old)>5){
      Serial.print("Effect1: ");Serial.println(effect1);
      setMidiControl(MIDI_EXPRESSION, 127-effect1*3/5, 0);
      effect1_old = effect1;
    }
    if (abs(effect2-effect2_old)>5){
      Serial.print("Effect2: ");Serial.println(effect2);
      setMidiControl(MIDI_PITCH_BEND, 0, (64-(effect2)/2), 0);
      effect2_old = effect2;
    } 
    velocity=AB::readVel(b);
    P.chordUpdate(velocity);
    if (abs(velocity-velocity_old)>20){
      velocity_old = velocity;
    }
    if (not digitalRead(DB[B_MELODY])){
      loopB_Melody();
    }
    
    //Chord shape change
    myPiano.chordRefresh();
 
    delay(10);
  } while(velocity>0 or effect1 >0 or effect2 > 0);
  P.chordStop();
  SR_blank();
}

void loopB(){ //Play music based on button presses
  //Waiting mode. No key pressed
  
  for (int i=0; i<NB_AB; i++){
    int v = AB::readVel(i);
    if (v){
      Serial.print("Chord ");Serial.println(i);
      loopB_Chord(i, v);
      Serial.println("Chord finished");
      break;
    }  
  }  
  if (not digitalRead(DB[B_RYTHM])) {
    //loopB_Rythm();
  } else if (not digitalRead(DB[B_VOL])){
    loopB_Volume();
  } else if (not digitalRead(DB[B_MELODY])){
    loopB_Melody();
  } else if (not digitalRead(DB[B_TRANSP])){
    loopB_Instr_Transpose();
  }
#ifdef OUT_USB
    MidiUSB.flush();
#endif
  delay(10);
}

///////////////////////////////////////////////
///////////////////////////////////////////////
void loop() {loopB();}

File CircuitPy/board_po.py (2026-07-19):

#This file centralizes all the hardware-related configuration (incl. the pin allocation and calibration) in one location, and does pin initialization when needed
import board, digitalio, analogio, busio, neopixel, adafruit_midi, usb_midi
from version import version
#Hardware versions start at 31

#TODO:
# * If no version.py file, exit gracefully with an error message displayed on the OLED screen
# * address bits A and C are swapped. Correct them, and correct the keyb_map as well to make all the keys work the same

verbose = False

#Helper functions
def pinOut(p, value=None):
    ret = digitalio.DigitalInOut(p)
    ret.direction = digitalio.Direction.OUTPUT
    if value != None: ret.value = value
    return ret

def pinIn(p, pull=None):
    ret = digitalio.DigitalInOut(p)
    if pull != None: ret.pull = pull
    return ret

#OLED Display on SPI bus
disp_CLK  = board.GP10 if version>=31 else board.GP6
disp_MOSI = board.GP11 if version>=31 else board.GP7
disp_DC   = board.GP9  if version>=31 else board.GP5
disp_CS   = board.GP8  if version>=31 else board.GP4 if version>=25 else board.GP3
disp_RST  = board.GP12 if version>=31 else board.GP20 if 25==version else board.GP8
#MIDI out. Select between UART (on-board synth) and USB MIDI
midi = [ adafruit_midi.MIDI(midi_out=usb_midi.ports[1]),
         adafruit_midi.MIDI(midi_out=busio.UART(tx=board.GP16, baudrate=31250), debug=False)
         ]

# Backlight
# pixel sequence: [6, 7, 5, 4, 2, 1, 0, 3, 10, 9, 8, 11, 12, 13]
# index            0  1  2  3  4  5  6  7   8  9 10  11  12  13
backlight_map = [6, 5, 4, 7, 3, 2, 0, 1, 10, 9, 8, 11, 12, 13] 
backlight = neopixel.NeoPixel(board.GP0, len(backlight_map), brightness=.25, auto_write=False)

# Key indices (keyboard bitmap) and backlight hint masks
KEY_THIRD = 8
KEY_FIFTH = 9
KEY_SEVENTH = 10
KEY_SHIFT = 11
KEY_SHARP = 12
KEY_MINOR = 13
KEY_NOTE_MASK = 0xFF
LOOP_SLOTS = 0x3F  # note keys 0-5 used for looper

#Buttons
power_off = pinOut(board.GP13, value=False) #Set to high to turn off
force_on  = pinOut(board.GP14, value=False) #Set to high to keep the user from turning off the instrument
key_vol   = pinIn(board.GP18, pull=digitalio.Pull.UP)
key_loop  = pinIn(board.GP19, pull=digitalio.Pull.UP)
key_instr = pinIn(board.GP20, pull=digitalio.Pull.UP)
key_capo  = pinIn(board.GP21, pull=digitalio.Pull.UP)

# Strum comb — Holtek BS8112A-3 (V32+: SCL=GP7, SDA=GP6). Older boards: no I2C.
if version >= 32:
    strum_i2c = busio.I2C(scl=board.GP7, sda=board.GP6)
else:
    strum_i2c = None
STRUM_I2C_ADDR = 0x50  # Holtek default (0xA0/0xA1 with R/W)
STRUM_N_KEYS = 12
# Musical low->high pad order as BS8112A Key numbers (1..12). Slot 0 = lowest note = Key10.
STRUM_KEY_MAP = (10, 9, 8, 7, 6, 5, 4, 3, 11, 12, 1, 2)

#Analog keys keyboard (also provides battery and USB voltage readings)
keyb_muxA = pinOut(board.GP1)
keyb_muxB = pinOut(board.GP2)
keyb_muxC = pinOut(board.GP3)
keyb_ADC = [analogio.AnalogIn(board.A0),
            analogio.AnalogIn(board.A1)]
# Hall sensor supply: GP4 high = off, low = on (V31+ only; GP4 is display CS on older boards)
keyb_vbus = pinOut(board.GP4, value=True) #Power supply for the hall sensors
vbat_addr = 9
vusb_addr = 13

#Anolog key addresses
#keyb_map = [ 5,  9,  1, 13,  4,  8,  0,  12,   2,    15,  11,      6,  14,  10,   3,  7]
keyb_map = [ 5,  3,  1,  7,  4,  2,  0,   6,   8,    15,  11,     12,  14, 10,   9,      13] # address of each key
key_names =["C","D","E","F","G","A","B","CC","SUS","Aug","7th","Shift","#","m","vBat", "vUSB"]
#Index       0,  1,  2,  3,  4,  5,  6,   7,   8,    9,   10,     11,  12, 13,  14,      15 
key_up   = 10
key_down = 13

#Analog keys calibration, obtained with calibrate() in keyboard.py
keyb_range=[10701, 6865, 7111, 8464, 11984, 8133, 8056, 9194, 11700, 1, 6288, 6473, 8403, 147, 9041, 11070]; keyb_min=[11985, 10388, 11574, 11325, 13791, 9424, 10333, 9747, 15483, 6314, 9892, 9892, 12139, 909, 11596, 11424] #V32-A
#keyb_range=[8533, 11101, 6973, 10148, 8379, 7749, 9178, 9209, 13845, 1, 6650, 6496, 9801, 16, 8079, 11016]; keyb_min=[10743, 11616, 10599, 11937, 10209, 9583, 10570, 10315, 16538, 6786, 10458, 9972, 10507, 288, 10725, 12413] #V31-1
#keyb_range=[10291, 10674, 14523, 24, 8730, 7090, 17060, 32, 7786, 8434, 7754, 9563, 8034, 7658, 8818, 8858]; keyb_min=[10946, 9290, 12459, 6890, 9618, 10290, 13835, 488, 9346, 8626, 8866, 11026, 9394, 9602, 10234, 9282] #V31-2

#End

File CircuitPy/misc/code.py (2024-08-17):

import digitalio, board
import time, supervisor

def pinOut(p, value=None):
    ret = digitalio.DigitalInOut(p)
    ret.direction = digitalio.Direction.OUTPUT
    if value!=None:
        ret.value =value
    return ret

def check_power_button():
    if not(power_button.value):
        t0=supervisor.ticks_ms()
        LED.value=False
        print("Power pressed")
        while supervisor.ticks_ms() - t0 < 200:
            if not(power_button.value):
                print("Power released")
                return
        print("Turning off now")
        power.value=False

LED = pinOut(board.GP25, value=True)
power = pinOut(board.GP10, value=True)
#power_button = digitalio.DigitalInOut(board.GP11)
#digitalio.Pull.UP #Pulled up by the power pin already.
power_button = digitalio.DigitalInOut(board.GP12) #debug

print("Turned on")

while True:
    check_power_button()

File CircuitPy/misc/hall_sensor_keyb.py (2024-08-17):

#This module drives the 14 analog keys with Hall effect sensors.
#The keys are multiplexed (address is set through mux_A, _B, and _C)
#and readings are collected through two ADCs.
#
# Key order is:
# 0~7: the note keys (C, D, E.. CC)
# 8~13: the left-hand keys (left to right, top to bottom)
#
# The magnets must be installed in the right direction (pressing down the key lowers the reading)

from board_po import keyb_muxA, keyb_muxB, keyb_muxC, keyb_ADC, keyb_min, keyb_max, keyb_map
import time, supervisor

class Keyb:
    def __init__(self):
        self.values = bytearray(16) #analog values
        self.map = [keyb_map.index(i) for i in range(16)]#compute reverse map once for faster reading in loop()
        self.bitmap = 0#of button press states
    
    def _read_addr(self, addr):
        keyb_muxA.value = addr&0x8
        keyb_muxB.value = addr&0x4
        keyb_muxC.value = addr&0x2
        #time.sleep(0.001)
        keyb_ADC[addr&0x1].value
        return keyb_ADC[addr&0x1].value
    
    def read_val(self, key):
        "Return an 8-bit reading"
        addr = keyb_map[key]
        return max(0, min(255,255-(((self._read_addr(addr)-keyb_min[addr])<<8)//keyb_max[addr])))

    def loop0(self):
        "Read all values -- naïve"
        self.bitmap = 0
        for i in range(16):
            self.values[i] = self.read_val(i)
            self.bitmap |= (self.values[i]>64)<<i

    def loop(self):
        "Read all values -- optimized"
        self.bitmap=0
        for i in range(8):
            keyb_muxA.value = i&0x4
            keyb_muxB.value = i&0x2
            keyb_muxC.value = i&0x1
            for j in range(2):
                addr=self.map[(i<<1)+j]
                self.values[addr] = max(0, min(255,255-(((keyb_ADC[j].value-keyb_min[addr])<<8)//keyb_max[addr])))
                self.bitmap |= (self.values[i]>64)<<i
            

def monitor_readings(val = range(14)):
    "Print raw 16-bit values for all [listed] keys in order"
    k = Keyb()
    while True:
        print([k._read_addr(keyb_map[i]) for i in val])
        time.sleep(0.1)

def monitor_values(val = range(14)):
    "Print the 8-bit values from all [listed] keys, after calibration and in order"
    k = Keyb()
    while True:
        print([k.read_val(i) for i in val])
        time.sleep(0.1)

def calibrate():
    "Press each key all the way down in turn, then copy-paste the output into board_po.py, variables keyb_min and keyb_max"
    k = Keyb()
    vmin = [66000]*16
    vmax = [0] * 16
    while True:
        for i in range(16):
            r = k._read_addr(i)
            vmin[i] = min(r, vmin[i])
            vmax[i] = max(r, vmax[i])
        print("keyb_min=",vmin, ";keyb_max=",[vmax[i]-vmin[i] for i in range(16)])
        time.sleep(0.1)

def test_loop():
    k = Keyb()
    while True:
        t0=supervisor.ticks_ms()
        k.loop0()
        #print([k.values[i] for i in range(14)])
        #print("{0:b}".format(k.bitmap))
        #Timing measurement
        k.loop0();k.loop0();k.loop0();k.loop0();k.loop0();k.loop0();k.loop0();k.loop0();k.loop0();print("{}ms/run".format((supervisor.ticks_ms()-t0)/10))
        time.sleep(0.1)

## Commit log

2019-06-22 Create Enclosure_V7_2019-Apr-29_12-07-00PM-000_CustomizedView14626299454.png
    Added 3D image
2019-06-23 Added PCB design link
2019-06-29 Rename/move for Arduino IDE compatibility
2019-07-07 Added support for storage to I2C EEPROM
2020-04-04 V11: switch to STM32 & capacitive keys
    [BOM_Pocket_Organ_2020-03-21_20-22-19.csv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]
2020-05-14 New hardware iteration
    [BOM_Pocket_Organ_2020-04-05_21-22-53.csv, BOM_Pocket_Organ_2020-04-25_23-08-30.csv, BOM_Pocket_Organ_2020-05-11_22-03-17.csv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]
2020-05-20 1st version
    Trial, for making more beautiful prototypes
2020-05-24 Split up the sliders into individual pads
    also added calibration
    It's now working, but the lag is too high (70ms)
    [keyboard.py]
2020-05-24 Data loss. Will fix later.
    [midi.py]
2020-05-30 Cleanup & robustification
    Move instrument names to a separate file, add data range checks to avoid hard-to-debug issues.
    [instr_names.py, midi.py]
2020-05-31 Fixed some of the key assignments
    [keyboard.py]
2020-05-31 fixed data corruption, more key shapes
    [polyphony.py]
2020-06-06 Initial version
    [BOM cost estimate (mass production).xlsx]
2020-06-13 Fix backlight, integrate it
    [backlight.py, keyboard.py]
2020-07-05 Calibration tweaks
2020-07-05 Revert "Calibration tweaks"
    This reverts commit 020a3bb4174c837af0b782770f3db8a7df6310b1.
    [keyboard.py, looper.py, metronome.py]
2020-10-07 V15
    Moved the assembly screw holes to the new (V14) position, created a slit for the strumming pins (15).
    [Pocket organ V15 enclosure v2.step]
2020-10-07 As ordered for V15
    Fixed some bugs.
    Moved to 3* AT42QT1110 touch sensors, two for the keys and one for a new set of strumming pins.
    This is a trial version, I temporarily removed the note key backlights.
    [BOM_Pocket_Organ_2020-09-26_18-20-36.csv, PickAndPlace_Pocket_Organ_V15_2020-09-26_18-21-02.csv]
2020-10-07 Added some error handling code
    [display.py]
2020-10-07 Flash IC support
    Added support for writing loops to a discrete flash IC over SPI bus, including a driver for the W25Q128 chip (16 MB).
    This code is fully working.
2020-10-07 fix for a nasty bug
    [metronome.py]
2020-10-07 Hardware workaround
    Pull up the Cable Select pins for all the peripherals on the SPI bus prior to initializing them. Only needed for board V15.
2020-10-07 Swap bass drum and snare keys, for playability
    [polyphony.py]
2020-10-11 Fixes
    fixed the AT42QT1110's footprint so I could assemble it (Doh!), and added a bunch of small correxions (like an easy way to pull up Boot0 or press the USR button from the original Pyboard, as well as a bunch of current-limiting resistors on digital lines.
    [BOM_Pocket_Organ_2020-10-11_20-20-49.csv, PickAndPlace_Pocket_Organ_V16_2020-10-11_20-20-42.csv]
2020-10-17 Group all pin & port creations in board.py
2020-10-17 V16 update
    [BOM cost estimate (mass production).xlsx, detailed PCB BOM with price estimates - V16.xlsx]
2020-11-15 Low-impedence "off" state for backlight
    Enable OE when the display is off, to avoid the need for grounding capacitors on each backlight LED (to limit interferences with the keypad)
    [looper.py, polyphony.py]
2020-12-05 Add board versionning
2021-02-21 Fix timing issue with "quick loop" mode
    [metronome.py]
2021-03-21 V17 PCB and enclosure
    Complete redesign
    [BOM_Pocket_Organ_V17_2021-03-17.csv, Bottom v7.step, Enclosure V17 v7.step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]
2021-03-21 V17 enclosure and PCB design
    complete redesign
    [Pocket organ V17 enclosure v6.stl, Pocket_Organ_V17_2021-03-17.pcbdoc]
2021-04-04 V17 support
    Plus, moving a bunch of thing to board.py that should have been there all along.
2021-04-04 Switch to bytearrays to save memory
2021-04-04 Add individual note key calibration
2021-04-05 Volume slider calibration moved to Board
2021-05-04 V18 enclosure
    [Pocket organ V18 V8 bot.step, Pocket organ V18 enclosure (redone) v9.f3d, Pocket organ V18 v8 top.step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]
2021-05-04 Freeze all the code!
    Load from filesystem first, from frozen code next.
    Also updated startup sequence to account for capacitive buttons
2021-05-04 move to Board, add V18 support
2021-05-05 Ready for UV printing
    [Pocket organ V19 v2 for printing.f3d, V19 bottom.step, V19 top.step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]
2021-05-08 implement battery gauge
2021-05-08 UV printing experiment
2021-05-09 UV printing - 1st trial
2021-05-16 Update strum board for V18
2021-05-16 Update strumming board for V18
2021-05-16 Fix and update status display
    [display.py, looper.py]
2021-06-12 improve key calibration on start-up
2021-07-24 Update keyboard_AT42QT1110.py
    Improve key sensing (hysteresis, self-calibration)
2021-08-29 Redone accidentals logic & calibration
    Now exclusively press on Do Fa, or Ut to bend up/down ; press on combinations of adjacent (exclusively) keys to get a semitone.
2021-08-29 New HW enclosure revision
    backward-compatible with V18 (need to cut off a screw pillar from the top cover).
    Same function, better looking.
    [Pocket organ V19B Bottom.f3d, Pocket organ V19B Bottom.stl, Pocket organ V19B Top.stl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]
2021-09-19 V19 new PCB
    [BOM_Pocket_Organ_V19_2021-09-15 (1).csv, PickAndPlace_Pocket_Organ_V19_2021-09-15 (1).csv]
2021-09-19 V19 PCB
    [Pocket_Organ_V19_2021-09-19.pcbdoc, Pocket_musical_instrument V18_2021-09-19.schdoc]
2021-09-19 Cleanup and minor corrections
    [backlight.py, display.py]
2021-10-30 Doc update
    [BOM cost estimate (mass production).xlsx]
2021-10-30 Remove support for versions <18, add v19 slider calibration
    Move version info to version.py
2021-10-31 V20 propotypes
    [BOM_Pocket_Organ_V20_2021-10-31.csv, PickAndPlace_Pocket_Organ_V20_2021-10-31.csv]
2021-11-05 Added 3D models, for 3D printing
    [Pocket organ V20 bottom.step, Pocket organ V20 v1 Top.step, Pocket organ V20 v1.f3d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]
2021-11-07 Add temporal & value filtering to the volume slider display
    Reduces flickering while adjusting the volume
2021-11-22 Fix & improve strumming
    [polyphony.py]
2022-01-04 Battery discharge tests - 1st round
    [V20 discharge curve - 1st test.xlsx]
2022-01-04 Fix strumming release bug - temporary solution
    Stop playing strummed keys when starting a new chord or changing chord shape, to avoid cases where a note is never released.
    Not fully satisfactory, need to also restart playing the strummed strings immediately, and maybe even not release the notes that are common to both the old and new chord's strummed strings.
    [polyphony.py]
2022-02-04 Larger erase blocks->much faster track erase
2022-02-05 Allow deleting a track while it's playing
2023-11-19 Moving to V23
    [PCB outline.dxf, Upper shell.stl, V20 discharge curve - 2nd test.xlsx]
2024-08-17 V26 model
    [bottom.stl, top.stl]
2024-08-17 V26 hardware with CircuitPython
2024-08-18 V26 3D models and doc upload
    [top.stl]
2024-08-18 Additional instructions for V26 assembly
2026-06-28 Update the shell 3D models
    [Pocket Organ V28 top.stl, top.stl]
2026-06-28 Code cleanup
    import board_po as board
2026-07-03 Fix the volume buttons
    Change from # and m to m and 7, to align with the melody bend keys.
    [Pocket Organ V28 top.stl, top.stl]
2026-07-03 Fix melody mode octave shift bug
    [pocket_organist.py, polyphony.py]
2026-07-05 Fixed the key backlight for the looper
    [backlight.py, board_po.py, looper.py]
2026-07-11 Fix the "division by zero" looper bug
    [looper.py]
2026-07-12 Fix metronome on/off issues
    [looper.py, metronome.py, pocket_organist.py]
2026-07-12 Display related patches and minor useability bugfixes
    [display.py, pocket_organist.py]
